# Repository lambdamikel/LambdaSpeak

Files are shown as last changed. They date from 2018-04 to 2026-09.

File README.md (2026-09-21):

# LambdaSpeak 
## A Next-Generation Speech Synthesizer & PCM Sample Player for the Amstrad / Schneider CPC, Multitech Microprofessor, and ZX Spectrum 
#### Author: Michael Wessel (Original Hardware Design and LambdaSpeak Firmware)
#### Contributors: Dr. Stefan Stumpferl (LambdaSpeak ROM and |RSX Driver), Bryce (some brainstorming about the hardware)
#### License: GPL 3
#### Homepage: [Author's Homepage](https://www.michael-wessel.info/) 

### Latest News

09-20-2026: The 1985 Vector Head speaks, on LambdaSpeak

In 1985 I digitized a wireframe head by hand off a P.M. Computerheft
article about computer graphics, using tracing paper and graph paper,
and wrote a Locomotive BASIC 1.0 program on my Schneider CPC 464 to
draw it. It has been my logo ever since.

Forty years on it has been rewritten in Z80 assembler, animated, and
given a voice. The head is drawn in 0.18 seconds instead of the 13.2
the BASIC took, and you can type any sentence and have it spoken, with
the lips, the jaw, the chin and the eyes moving on the allophones.
The text-to-speech is the Naval Research Laboratory letter-to-sound
algorithm, adapted from the 1985 Amstrad SSA-1 driver, so it runs on
LambdaSpeak in SSA-1 mode.

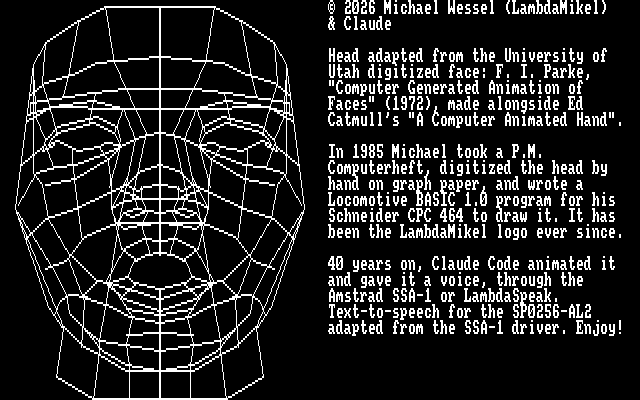
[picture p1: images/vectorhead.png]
The Vector Head


[Watch the YouTube demo video.](https://youtu.be/UzU3wziq7BQ)

[And here it is on LambdaSpeak 3.](https://youtu.be/XNuESTllX0o)

The disc is here: [head.dsk](cpc/vectorhead/head.dsk) for an emulator or a
real drive, and [head.hfe](cpc/vectorhead/head.hfe) for a Gotek or HxC.
Start it with `RUN"VH` - [here is how to run it.](cpc/vectorhead/) The
assembler source is not public yet.

12-16-2025: Direct Spectrum-to-CPC Adapter

This adds one Mx4 compatible expansion slot directly to the Spectrum,
without requiring the ribbon cable or Mx4-compatible backplane extender
(e.g., no LambdaBoard required). This looks much more organized indeed!

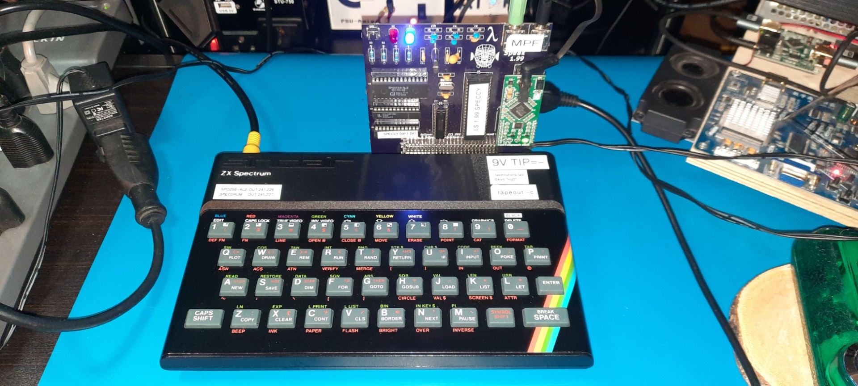
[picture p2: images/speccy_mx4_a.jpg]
Speccy Mx4 Adapter 1


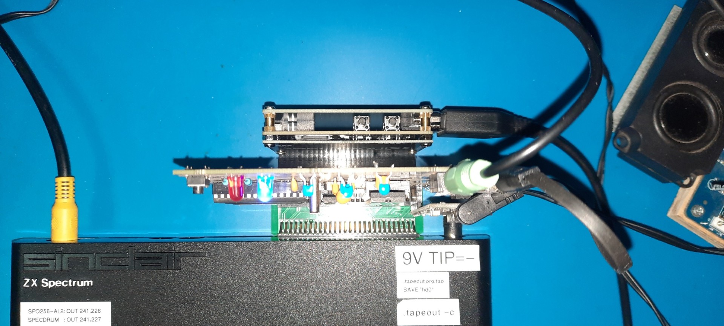
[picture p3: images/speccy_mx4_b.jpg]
Speccy Mx4 Adapter 2


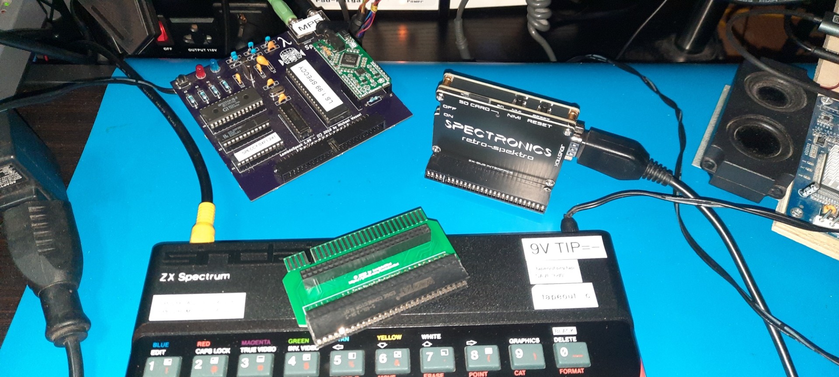
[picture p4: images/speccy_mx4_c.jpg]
Speccy Mx4 Adapter 3


[YT demo video.](https://www.youtube.com/shorts/BpbL_IXIipw?feature=share)

The Gerbers are [here](gerbers/zx-spectrum-mx4-direct-adapter-gerbers.zip)

12-07-2025: Cheetah Specdrum emulation is working:

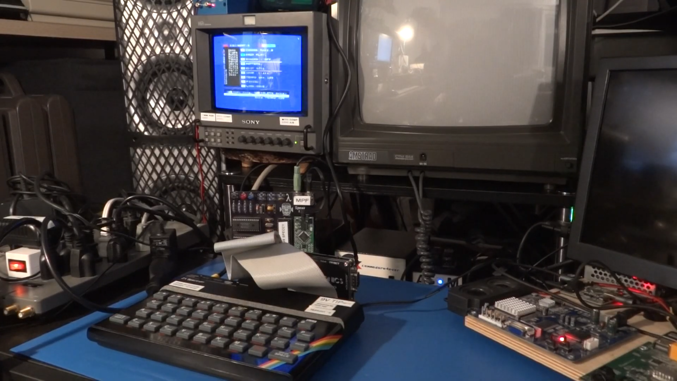
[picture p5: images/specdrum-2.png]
Specdrum 2

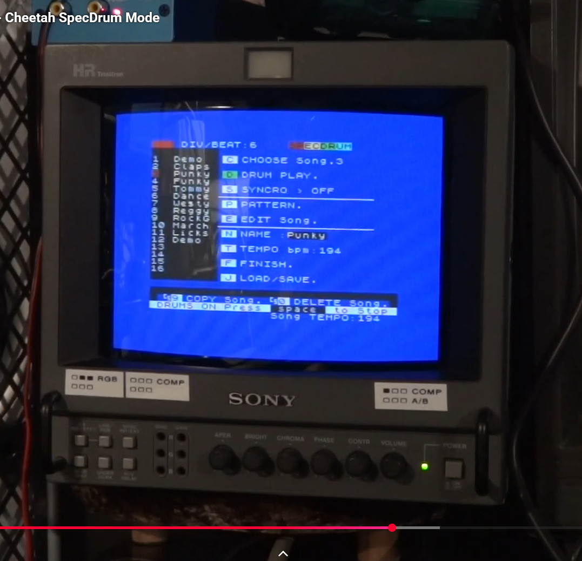
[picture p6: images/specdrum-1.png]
Specdrum 1


Check out [the SpecDrum emulation demo YouTube video.](https://youtu.be/OoMWcIEqiDU)

11-30-2025: I connected LambdaSpeak 1.99 to the ZX Spectrum!

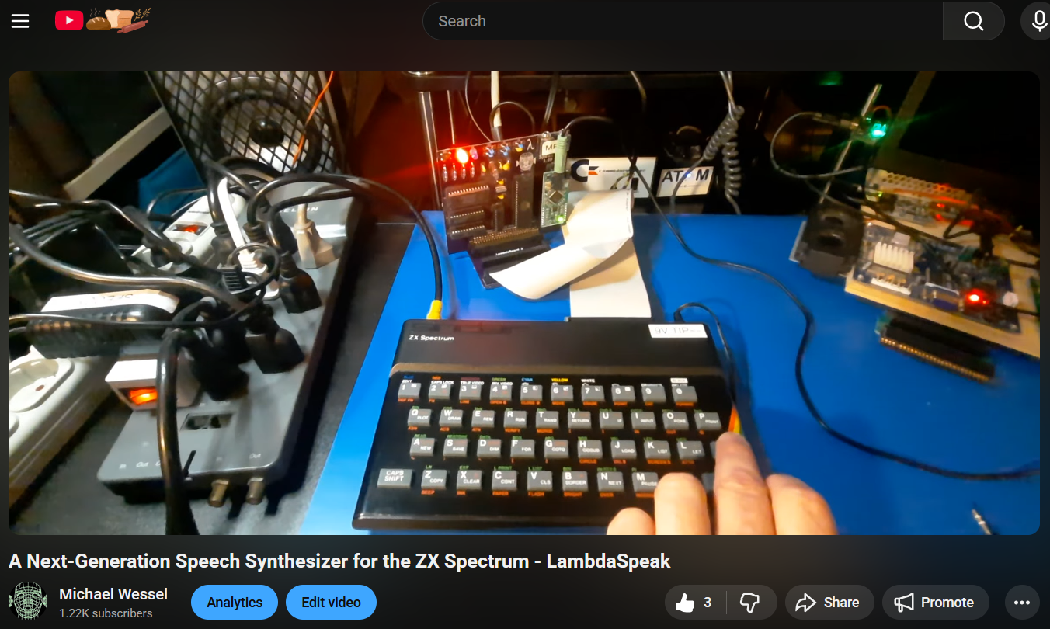
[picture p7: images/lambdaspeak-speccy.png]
LambdaSpeak 1.99 with the ZX Spectrum


[Watch the YouTube demo video.](https://youtu.be/x5bdC2Z1gy8)

To facilitate this, I have created a [ZX Spectrum to CPC Mx4 expansion
board adapter:](gerbers/zx-spectrum-adapter-gerbers.zip)

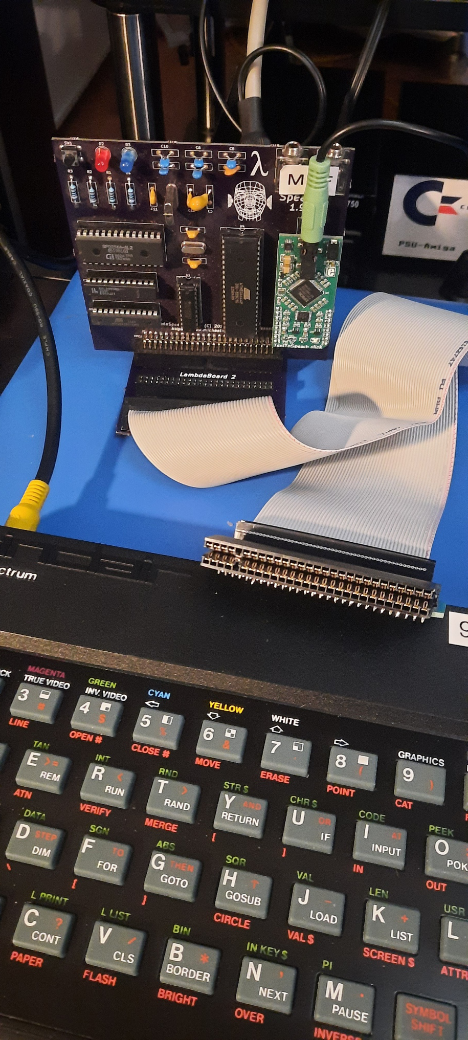
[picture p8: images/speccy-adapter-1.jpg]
Speccy Adapter 1

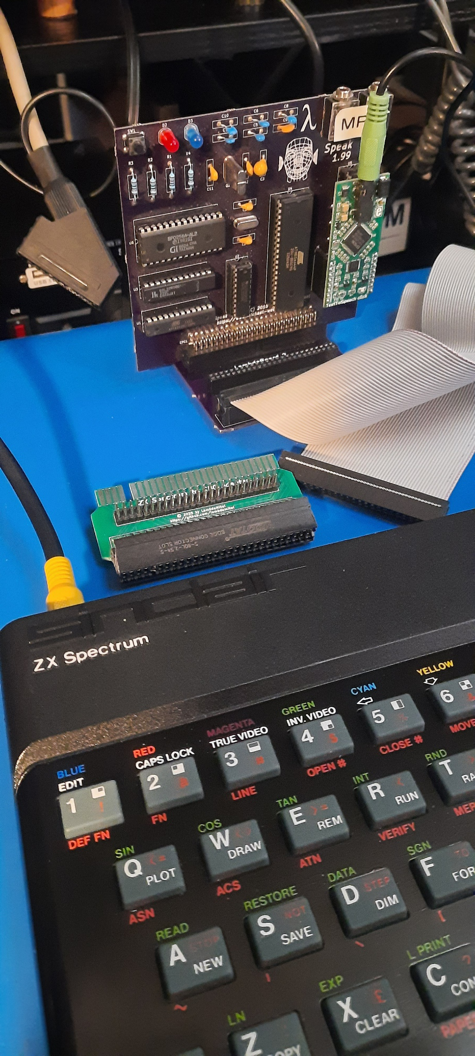
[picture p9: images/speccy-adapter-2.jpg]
Speccy Adapter 2


The adapter has a Speccy expansion port passthrough so that it will
work with other expansions as well (DivMMC, Interface I, ...). I have
only tested with the DivMMC so far, and no issues.

You will need an Amstrad CPC-compatible Mx4 expansion backplane, e.g.,
a [LambdaBoard](https://github.com/lambdamikel/LambdaBoard) or
[MegaLambda.](https://github.com/lambdamikel/MegaLambda-x6). Note that
the IDC female connector has the upper/lower pins flipped / mirrored, 
so you CAN NOT plug in the LambdaSpeak directly.

I changed the address decoder to listen to port `0x00F1` (`0xF1` =
`241`) for the Speccy. Also, only the non-blocking mode is working so
far - apparently, the Speccy doesn't like to be "halted". Hence, the
ATmega firmware needs a small change, too - see [line 5120 in the
`lambdaspeak.c` firmware:](src/atmega644-20pu/lambdaspeak.c)

```
	// note: for ZX Spectrum, remove / comment out this z80_halt: 
	z80_halt;
```

There is also a [ATmega HEX
image](firmware/atmega644/ls199-for-zx-spectrum-with-adapter/atmega644-20pu.hex)
and the [JED file for the `U1` address
decoder](firmware/ls199/gal22v10-zx-spectrum/LambdaSpeak-U1.jed) if
you want to try this yourself.

### Older News 

06-28-2025: I connected LambdaSpeak 1.99 to the Microprofessor. I
always longed for the SSB-MPF speech synthesizer with the TMS5200
chip, but they are pretty much unobtainium. But, LambdaSpeak 1.99 is
actually the better deal, due to natural sounding speech, built-in
text-to-speech (no allophone encoding required!), and in addition, is
also has the SP0256-AL2! My LambdaSpeak 1.99 was sitting unused in a
box for the last 7 years, and it was more than happy to shine again. I
needed to reprogram the GALs though; the address decoder listens to
port `0x00FE` now, and I removed all DK'tronics-related encoding as
well. It works!

https://www.youtube.com/watch?v=P0gi5Z2-3yM

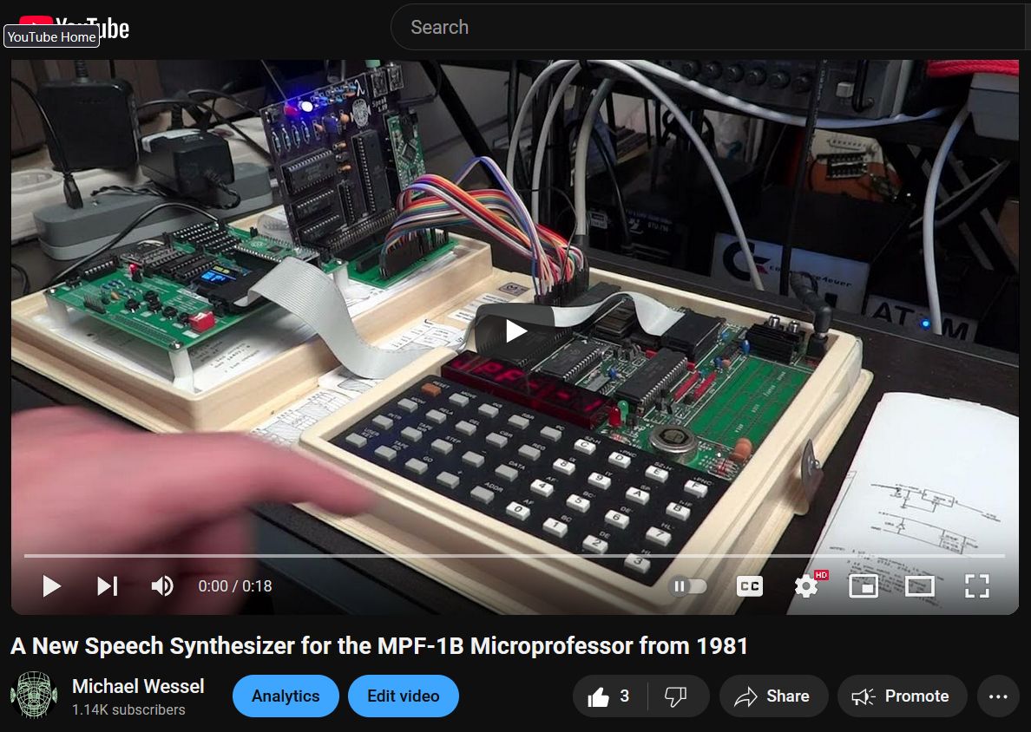
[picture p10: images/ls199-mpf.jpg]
LambdaSpeak 1.99 with the Microprofessor


The reprogrammed GALs are [here.](firmware/ls199/gal22v10-mpf/)

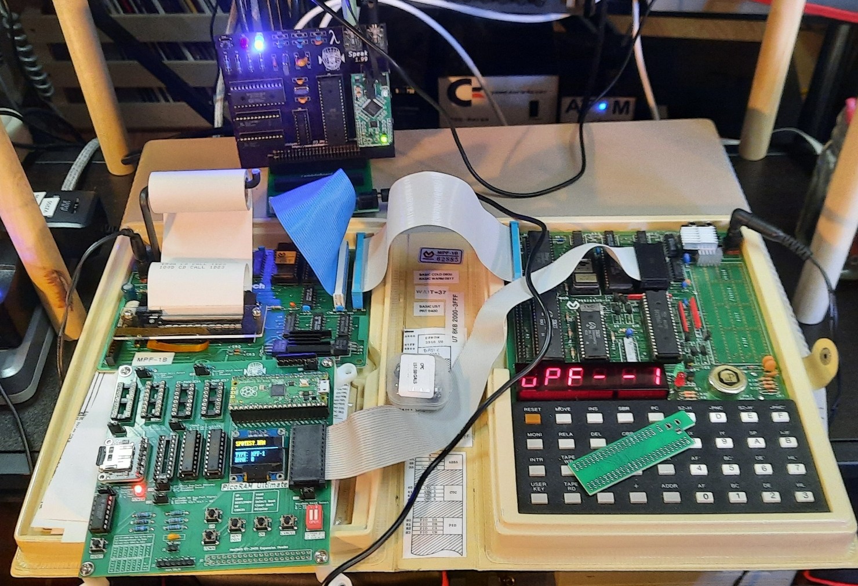
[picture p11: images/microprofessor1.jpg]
LambdaSpeak 1.99 with the Microprofessor 1

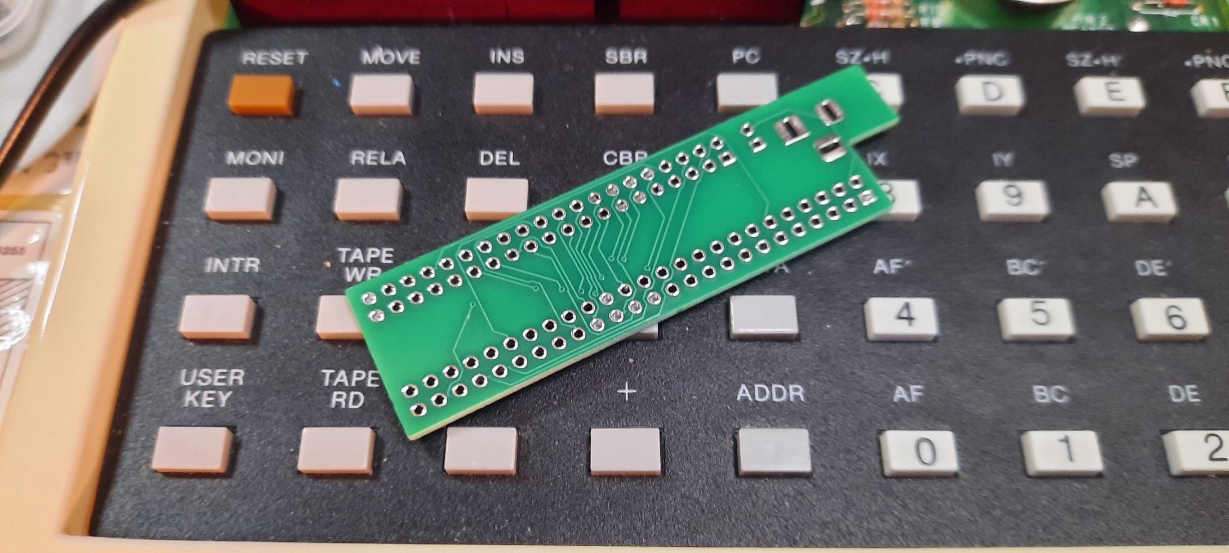
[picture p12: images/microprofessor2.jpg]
LambdaSpeak 1.99 with the Microprofessor 2

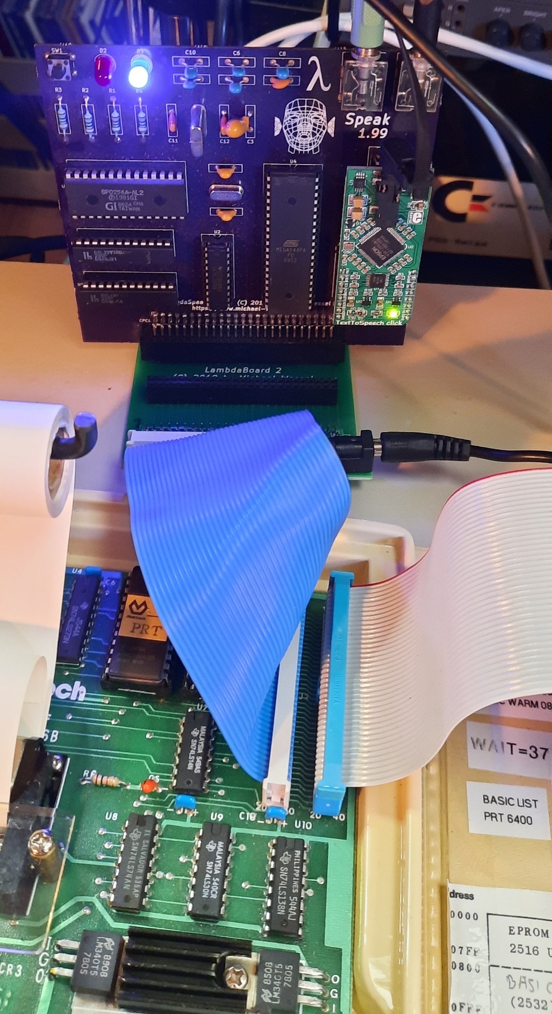
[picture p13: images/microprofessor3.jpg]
LambdaSpeak 1.99 with the Microprofessor 3

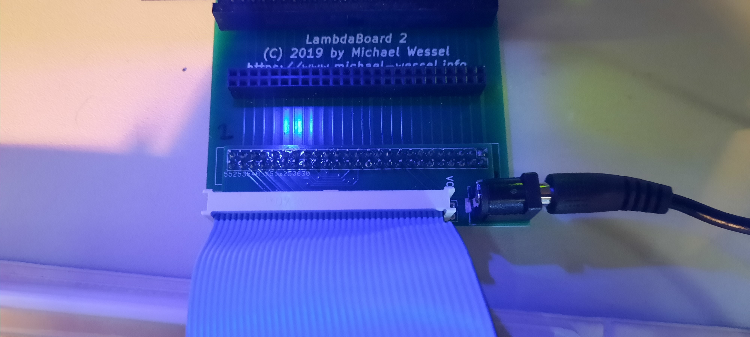
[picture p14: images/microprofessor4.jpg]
LambdaSpeak 1.99 with the Microprofessor 4


Here are [the Gerbers for the
adapter](gerbers/microprofessor-adapter-gerbers.zip), and here is
[a matching CPC backplane](https://github.com/lambdamikel/LambdaBoard). 

### Much Older News 

I have decided to publish [the WinAVR C sources for LambdaSpeak 1.95 and LambdaSpeak 1.99](src/atmega644-20pu/). The  [main C firmware file](src/atmega644-20pu/lambdaspeak.c) is shared among LambdaSpeak 1.95, LambdaSpeak 1.99, and LambdaSpeak 3, so please make sure to have `#define LS195` or `#define LS199` enabled.

### Important License Information

LambdaSpeak uses GPL 3. This code uses the [Epson S1V30120 firmware image]( https://github.com/MikroElektronika/Click_TextToSpeech_S1V30120/blob/master/library/include/text_to_speech_img.h)
from the [TextToSpeech click board library from MikroElektronika released under GPL2.](
https://github.com/MikroElektronika/Click_TextToSpeech_S1V30120) 
By using this code, you are also bound to the [Epson license terms for the S1V30120 firmware.](https://global.epson.com/products_and_drivers/semicon/products/speech/voice/sla/s1v30120_init_data.html)  

### Requirements 

This project was developed using
[WinAVR.](http://winavr.sourceforge.net/) In addition, the [AVR
Programming Libraries](https://github.com/hexagon5un/AVR-Programming)
from Elliot Williams' book "Make: AVR Programming" are being used. 

### Building and Maker Support 

I am able to provide LambdaSpeak 1.95 and LambdaSpeak 1.99 as a kit, or only pre-programmed components (CPLD, ATMega), or even a fully assembled version including
a connection cable and/or LambdaBoard expansion board backplane. Send me a mail if you are interested. Or, just download the sources and build it from the [provided Gerbers](gerbers/).

To build the [firmware from source,](src/atmega644-20pu/lambdaspeak.c) use `make` and the [provided `Makefile`](src/atmega644-20pu/Makefile). The makefile template is again from Elliot Williams' "AVR Programming" book. See below (Acknowledgements). 

### Introduction

**NOTE - This project is obsolete. Please refer to [the successor project, LambdaSpeak 3](https://github.com/lambdamikel/LambdaSpeak3)**

LambdaSpeak is a next-generation speech synthesizer and PCM sample player for the Amstrad CPC line of 8bit home computers from the 1980s (i.e, the CPC 464, CPC 664, and CPC 6128). 

LambdaSpeak is a MX4-compatible IO extension that plugs into the expansion port of the CPC.

LambdaSpeak is based on the **Epson S1V30120 TTS** (text to speech) chip. An **ATmega 644P-20PU** microcontroller clocked at 20 MHz is running the LambdaSpeak firmware, which implements a high-level intelligent interface to the CPC. The LambdaSpeak firmware / ATmega 644 is also responsible for hosting and loading the Epson firmware into the S1V30120, and for controlling the Epson speech chip via the SPI interface.  The Epson firmware is rather large; hence a microcontroller with a large (64 KB of) flash memory such as the ATmega 644 was selected. 

The Epson S1V30120 firmware implements two modes of operation: a DECtalk-compatible mode, and a simplified, native Epson mode. The latter is simpler and sometimes produces more accurate speech, whereas the former offers much more fine grained control over the speech synthesis process.  DECTalk is famous for being the "singing" speech synthesizer. 

LambdaSpeak 1.99 and LambdaSpeak 2.1 additionally feature the original **General Instruments SPO256-AL2 chip**, for 100% authenticity and compatibility with the original SSA-1 and DK'tronics speech synthesizers.  

### Features 

LambdaSpeak is a high-quality speech synthesizer for the Amstrad / Schneider CPC, based on the Epson S1V30120 speech chip. LambdaSpeak uses the [39$ "TextToSpeech click" board from MikroElektronika](https://www.mikroe.com/text-to-speech-click) as a daughter board. This board basically consists of the Epson IC, an op-amp, and an audio jack.  

LambdaSpeak also implements the **Amdrum module**, a PCM sample-based drum computer for the CPC. 

Optionally, LambdaSpeak can be equipped with a second speech chip, the original **SPO256-AL2** from General Instruments ano 1981.        

The following modes of operation are implemented by the **LambdaSpeak firmware** that runs on the ATmega 644:   

  1. **Native Epson Mode:** Native because the TTS is directly performed by the Epson IC / firmware. In this mode, a stream of ASCII characters can be sent to CPC IO port &FBEE, terminated by CR (13), and the assembled ASCII string will be spoken by LambdaSpeak. Voice, volume, and speed of the speech can be changed as well.  

  2. **Native DECtalk Mode:** The DECtalk emulation offers much more fine-grained control over different aspects of the generated speech. These aspects are specified using the standard DECtalk syntax, down to the level of phonemes if desired. In this mode, LambdaSpeak can even sing a song! Again, CPC IO port &FBEE is used. 
  
  3. **SSA-1 mode:** In this mode, LambdaSpeak emulates the **Amstrad SSA-1 Speech Synthesizer**. The SSA-1 synthesizer uses a very different speech chip, the **SPO-256 AL2 from General Instruments**. This chip offers phoneme-based speech synthesis. The emulation of the SSA-1 is achieved by translating SPO-256 AL2 phonemes into DECtalk phonemes. Whereas the SSA-1 works synchronously, i.e., a phoneme is immediately uttered as soon as it arrives at the port, this is not possible with the Epson chip. Hence, LambdaSpeak employs a phoneme buffer (of 380 characters) which is first filled with phonemes, and the buffer is flushed and spoken if no phoneme has arrived for a couple of milliseconds (the buffer flush delay time if configurable). The buffer is also flushed automatically when it overflows, and a corresponding "flush buffer" command / "control byte" also exists (see below). Hence, the SSA-1 emulation works asynchronously, and a slight delay between phoneme sending and speaking should be expected. The SSA-1 uses IO ports &FBEE and &FAEE.  Please note that it is impossible to emulate the low-quality robotic sound of the SPO-256 AL2 with a modern speech IC such as the Epson S1V30120. Hence, the SSA-1 emulation will actually produce understandable speech that sounds much better than the original, but it is not 100% authentic to the original. The emulation, due to its asynchronous character, is only 90%, but good enough for most of the SSA-1 driver |RSX commands and games to work flawlessly. See below for videos of the SSA-1 mode. 
       
  4. **DK'tronics mode:** In this mode, the **DK'tronics Speech Synthesizer** is emulated. The DK'tronics synthesizer uses IO port &FBFE. It is very similar to the SSA-1, and uses the same SPO-256 AL2 speech chip from General Instruments. However, the driver software and |RSX extension are different, and a different "protocol" is implemented. Unlike for the SSA-1, a ROM version of the DK'tronics driver software exists. The DK'tronics driver software implements a less advanced text-to-phoneme speech translation algorithm than the SSA-1 driver software; the latter sounds much better, IMHO. The LambdaSpeak implementation of the DK'tronics speech synthesizer works similar to the SSA-1 emulation, i.e., a phoneme buffer and auto-flushing (and speaking) of the phoneme buffer after a configurable flush buffer time delay of inactivity is performed. Similar comments regarding the authenticity and compatibility as for the SSA-1 mode apply to the DK'tronics emulation.

  5. LambdaSpeak 1.99 and LambdaSpeak 2.1 can be equipped with an optional **GI SPO256-AL2 speech chip**. Thus, a **SPO256-AL2-based SSA-1 mode** is offered, being 100% compatible and authentic to the original SSA-1. In this mode, LambdaSpeak can be considered a re-implementation of the original SSA-1. Unlike the Epson-based SSA-1 emulation, this mode works synchronous, like the original. 
  
  6. With the SPO256-AL2 speech chip being present, a **SPO256-AL2-based DK'tronics mode** is offered, which is 100% compatible and authentic to the original DK'tronics speech synthesizer. Like the SPO-based SSA-1 mode, this mode works synchronous as well, just like the original. 

  7. An 8bit PCM Sample Player, emulating the **Amdrum module**. In **Amdrum mode**, 8bit PCM samples can be sent to IO port &FFxx, which are being played immediately by LambdaSpeak. To quit this mode, LambdaSpeak needs to be power cycled (even the LambdaSpeak reset button is ineffective in this mode, as ATmega 644 interrupts are disabled for maximal sample playing quality). The PCM audio is produced by the ATmega 644 microcontroller.      

LambdaSpeak has an **op-amp-based audio mixer on board,** which is used to mix the PCM output with the (potentially present) SPO256-AL2 output and the speech audio from the "TextToSpeech click" daughter board. Since the audio output of the daughter board is **only** available from its audio jack, but not from the output header pins of the click board, a (short, e.g, 2") audio jumper cable has to be used to route its speech output into LambdaSpeak's audio input for mixing. 

### Media 

A couple of pictures and YouTube videos. Please notice that **the voltage SMD jumper of the TextToSpeech click daughter board must be set to the 5V position (requires soldering).**  

#### **LambdaSpeak 1.95**: 

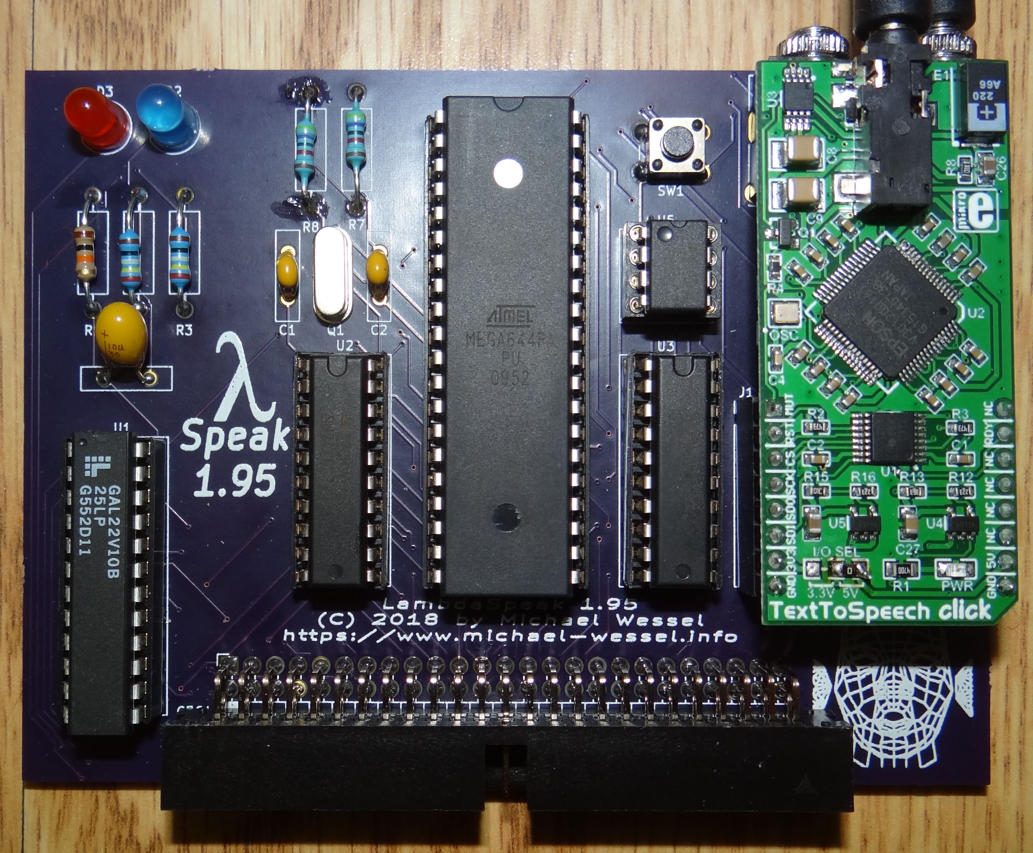
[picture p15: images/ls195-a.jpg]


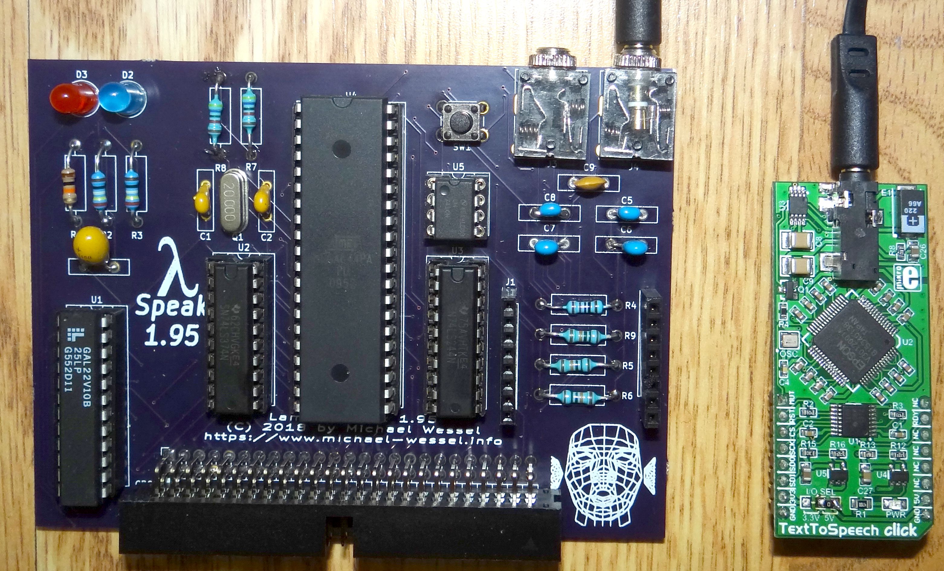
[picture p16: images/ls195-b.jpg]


#### **LambdaSpeak 1.99** with additional GI SPO256-AL2:   

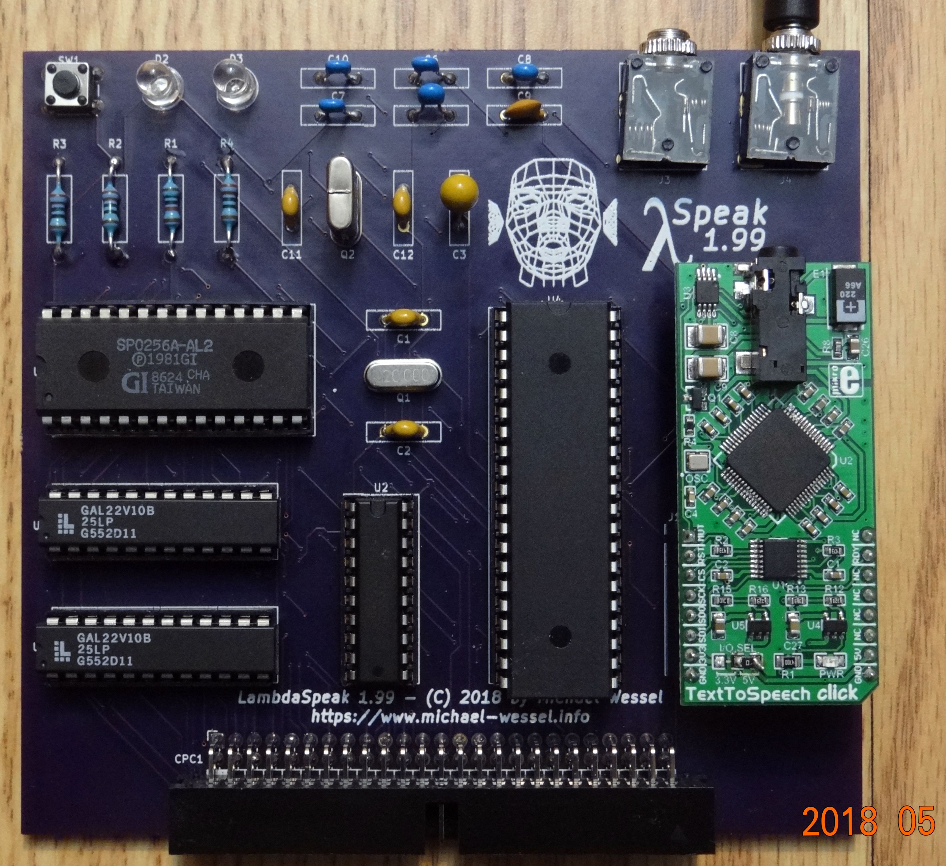
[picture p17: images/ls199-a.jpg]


#### CPC Connection: 

LambdaSpeak is **MX4 compatible** and can either be plugged into the Mother X4 board, a standard 50-pin ribbon cable, or my [MX4 compatible CPC 464 expansion port adapter for the CPC 464](https://oshpark.com/shared_projects/3yA33GYO) can be used:  

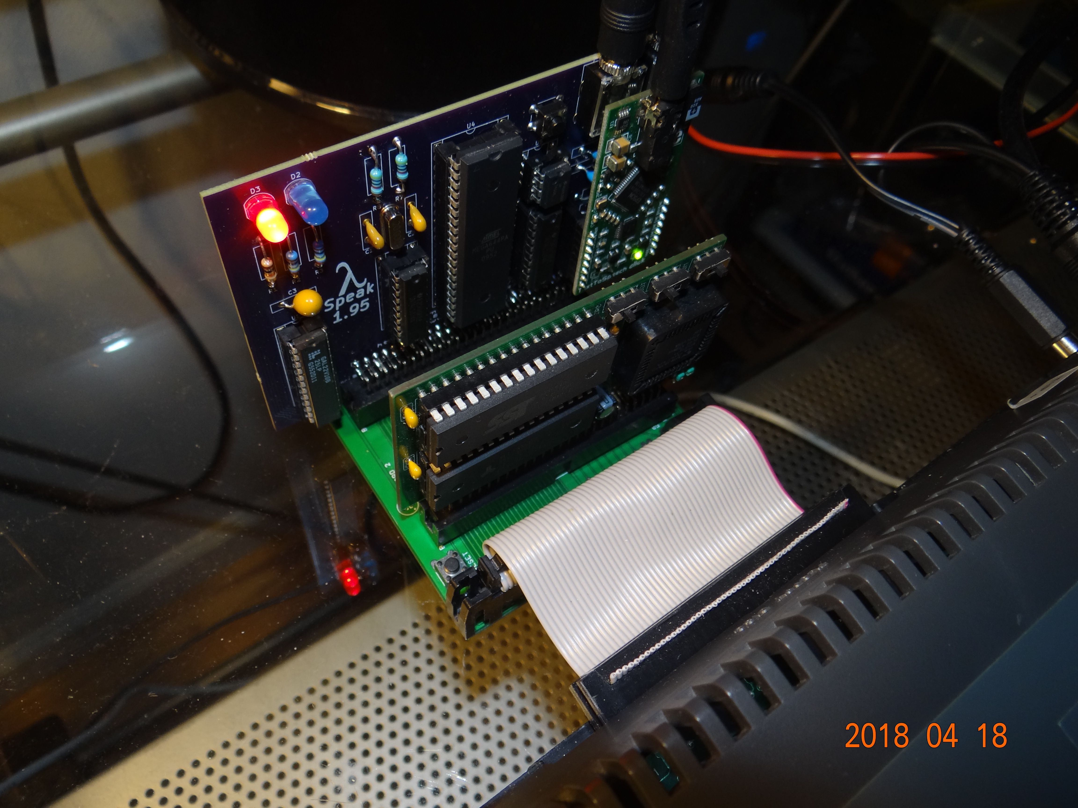
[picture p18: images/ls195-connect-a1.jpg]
LambdaSpeak & XMem in Mother X4 Board


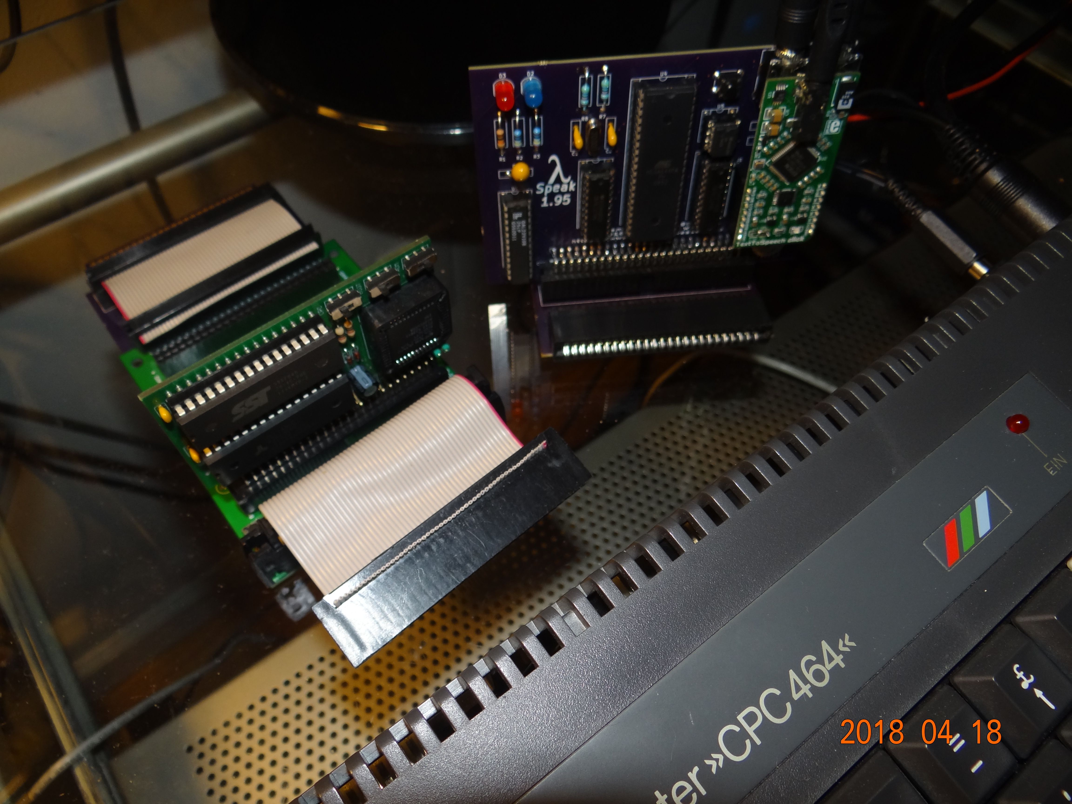
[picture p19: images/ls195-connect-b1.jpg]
LambdaSpeak & 464 Expansion Port Adapter


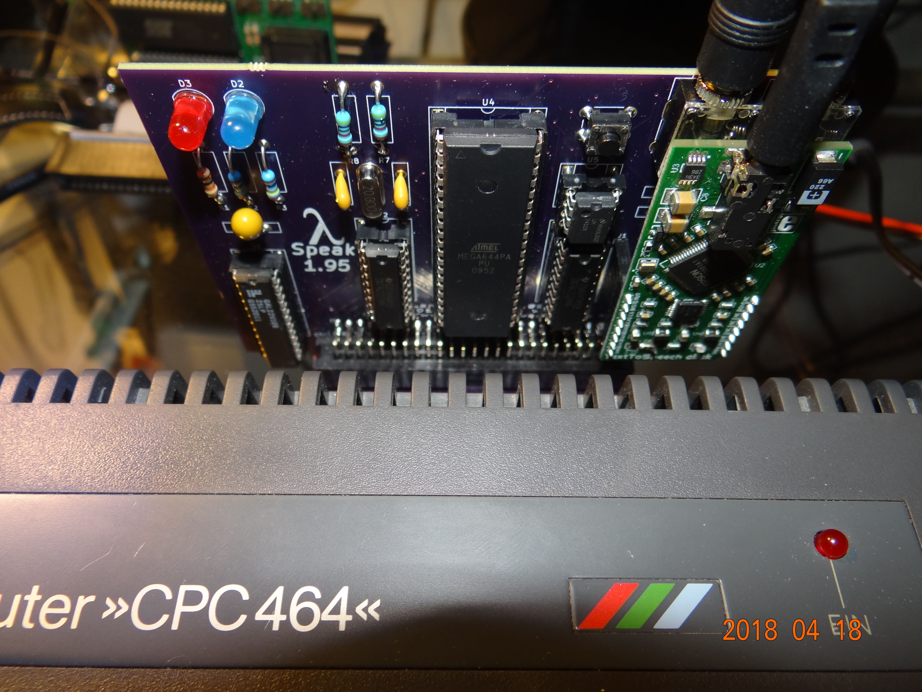
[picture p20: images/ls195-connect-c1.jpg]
LambdaSpeak & 464 Expansion Port Adapter in CPC


#### YouTube Videos 

Below are a couple of YouTube videos that demonstrate the various features and modes of LambdaSpeak. Notice that (some of) these videos are showing older versions of the LambdaSpeak hardware, but there is no difference in functionality. Also, speech quality etc. is identical to the current version of LambdaSpeak:  

- [LambdaSpeak Native Mode - talking ELIZA Program](https://youtu.be/ckCTHi5_2f8)
- [LambdaSpeak DK'tronics & SSA-1 Emulation - German-speaking ELIZA program, originally written for the DK'tronics speech synthesizer](https://youtu.be/aTxufTKfrYk) 
- [LambdaSpeak and DK'tronic Speech ROM Software](https://youtu.be/wxNSlEyfPMc)
- [TFM's LambdaSpeak |RSX Driver](https://youtu.be/CsaE9JfhJ20)
- [Sample Playing in "Amdrum mode" with TFM's |RSX Driver](https://youtu.be/RSu7fPpDmCQ)
- [PCM Audio Quality of Amdrum Mode using Amdrum Software](https://youtu.be/pBuBxT3YEuI)
- [Amdrum Demo](https://youtu.be/upVayBKlnow)
- [Another Amdrum Demo](https://youtu.be/E63uH6SpzMs)
- [LambdaSpeak 2.1 Breadboard Prototype with additional SPO256-AL2](https://youtu.be/Og3qyQo9nfw)

#### Older Versions

The historical **LambdaSpeak Ancestry Gallery** shows early versions of LambdaSpeak. Some early versions were using the **Emic 2** TTS daughterboad (bottom left PCB) instead of the "TextToSpeech click" from Elektronika: 

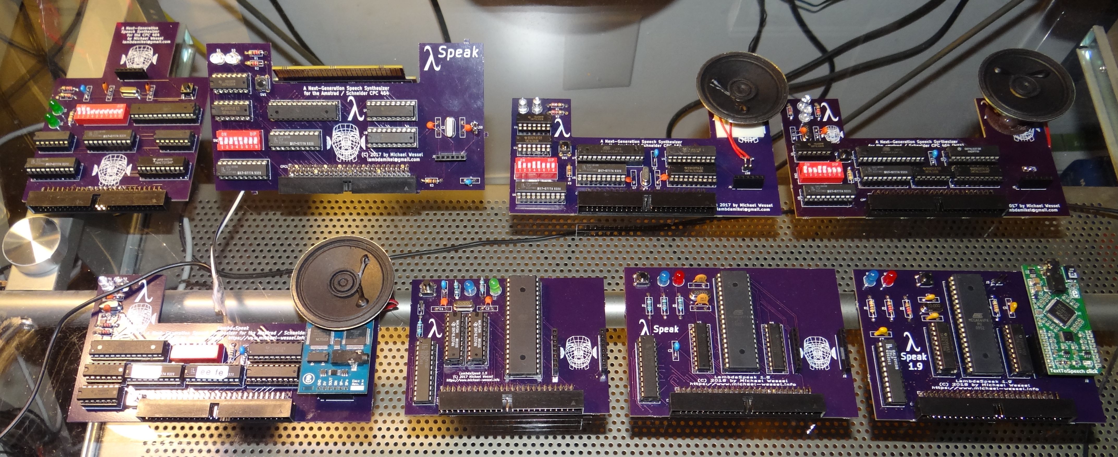
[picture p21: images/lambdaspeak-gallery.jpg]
LambdaSpeak Gallery


The versions, from top left to bottom right: 

 - LambdaSpeak 0 - no SSA1 or DK'tronics emulation, hand-soldered additional Z80 \_READY line at the bottom to correct for a design flaw. Emic 2 based, ATmega328p, 2 GAL16V8s. Not MX4 compatible. DIP switches are used to select port addresses etc. Clocked at 16 MHz. 
 
 - LambdaSpeak 1 - tried to make it fit with DDI3 display behind, but would still block the display due to miscalculation / bad measurements. SSA1 emulation required additional logic gate. Not MX4 compatible, \_READY line fixed. Added loudspeaker option. 
 
 - LambdaSpeak 1.2 - improvement over LambdaSpeak 1, no longer blocks DDI3 display. Otherwise identical to LambdaSpeak 1, but with little loudspeaker added. Loudspeaker can be en/disabled via DIP switch, DIP switches also select initial mode (SSA1 or native), Port Address, etc.
 
 - LambdaSpeak 1.3 - same as LambdaSpeak 1.2, but tried to make it MX4 compatible. Due to an error in the layout, it STILL was not MX4. Was working perfectly fine, just not MX4 compatible. 
 
 - LambdaSpeak 1.4 - the final version before hardware revision. Now MX4 compatible. 
 
 - LambdaSpeak 1.5 - new hardware version, triggered by input from Bryce who suggested to abandon the Emic 2 to bring the costs down (Emic 2 ~ 80 $). DKtronics emulation possible. No more DIP switches. Switched to ClickBoard! TextToSpeech daughter board, much cheaper than Emic 2, but requires bigger MCU now - selected the ATmega 644p with 64 KB @ 20 MhZ. A lot of flash memory is required to store and load the Epson S1V30120 speech IC firmware. Also, replaced the 2 GAL G16V8 and the glue logic with one GAL G22V10. <br /> In this version, the firmware supports DKtronics emulation by now. New design, uses 2 74LS374 flip flops instead of 1 74LS374 and 1 74LS244. Hence, chip count reduced from 7 to 4 (not counting the chips on the daughter boards). Also, the databus to the ATmega 644 is shared. Requires rather complicated triggering of input / output flip flops from the ATmega, and toggling of ATmega data port between input and output mode. Works, but too cumbersome and not as fast due to complicated clocking required for the flip flops. But easier to layout, as most of the ATmega 644's pins are unused. No more loudspeaker; audio jack output from speech daughter board. Clocked at 20 MHz.
 
 - LambdaSpeak 1.8 - switched back to having 1 74LS374 input flipflop and 1 74LS244 output driver with dedicated, permanent data connection to the ATmega instead of 2 flip flops with shared data bus. Requires no complicated flip flop clocking / control from the ATmega, but takes more lines. Faster.
 
 - LambdaSpeak 1.9 - early version, with Amdrum emulation / Sample Player output, suggested by zhulien. Firmware supports PCM sample playing and Amdrum emulation mode. Dedicated RC and line output for PCM via simple pin header on the board, no audio jack yet, and no audio mixer on board. The PCM header is on the left top next to the daughter board. Speech daughter board has independent audio jack output, of course. 
    
### Hardware Overview 

In the following, 4 versions of LambdaSpeak are being discussed:

* **LambdaSpeak 1.95 and LambdaSpeak 1.99** use through-hole components and GAL22V10 PLDs, and PCBs and Gerber files exist. LambdaSpeak 1.99 supports the SPO256-AL2 as a second (optional) speech chip. 

* **LambdaSpeak 2.0 and LambdaSpeak 2.1** only exist as (fully functional) breadboard prototypes. They use a single Xilinx XC9572XL CPLD instead of the GALs. No PCBs or Gerber files exist yet. Bryce suggested to use a Xilinx CPLD. LambdaSpeak 2.1 supports the SPO256-AL2 as a second (optional) speech chip.  

Let us discuss these versions in more detail in the following.

All LambdaSpeak versions require the Epson S1V30120 Text-to-Speech Speech Synthesizer IC. The [39$ "TextToSpeech click" board from MikroElektronika](https://www.mikroe.com/text-to-speech-click) is used as a daughter board. It is plug and play, but requires re-soldering of an SMD jumper (from 3.3 V to 5 V position).   

#### LambdaSpeak 1.95 Overview

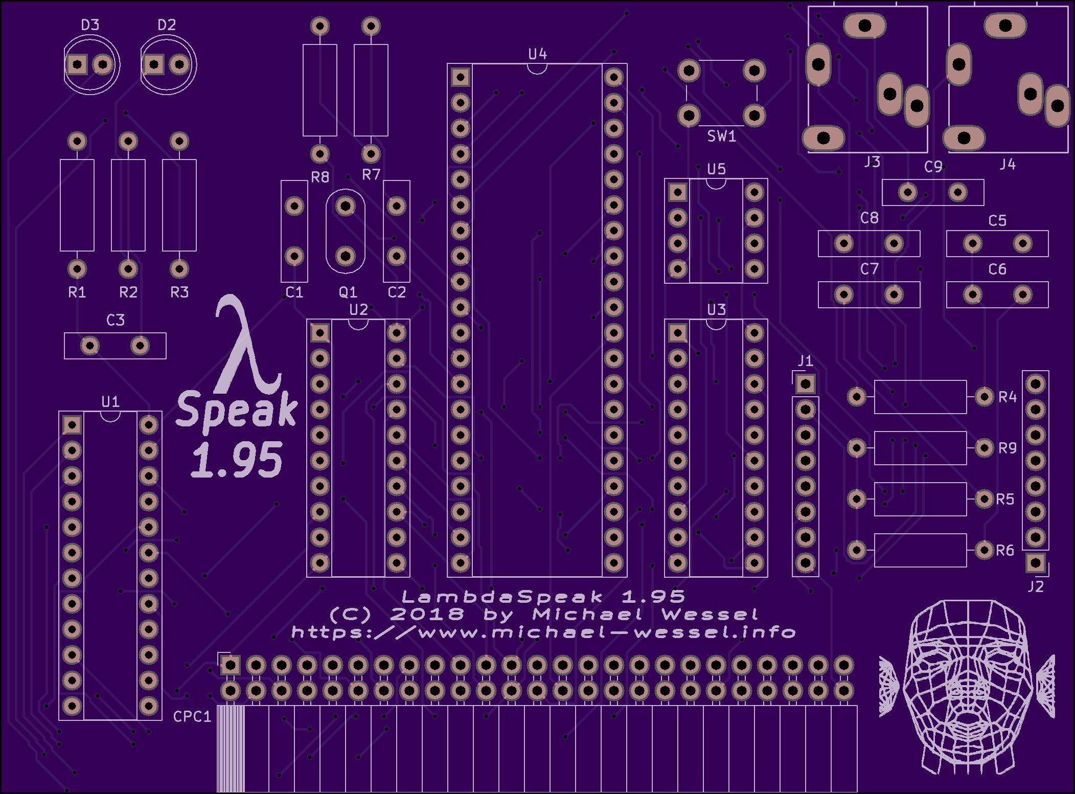
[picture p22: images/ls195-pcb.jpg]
LS 1.95 PCB


The main components are:

1. The [TextToSpeech click board from MikroElektronika](https://www.mikroe.com/text-to-speech-click) is used as a daughter board.  
2. ATmega 644P-20PU Microcontroller clocked at 20 MHz (U4). 
3. GAL22V10 Programmable Logic Device (U1), for Z80 address decoding and some glue logic. This is a discontinued component, but still easy to get on EBay. 
4. A 74LS374 flip flop (U2) for latching and buffering (input from) the CPC databus (handles IO write requests).
5. A 74LS244 bus driver (U3) for putting data on the CPC databus (handles IO read requests).
6. A LM741CN op-amp (U5) for mixing PCM output (produced by the ATmega 644) with the speech output from the Epson S1V30120 such that only one audio cable from LambdaSpeak is required. 

LambdaSpeak 1.95 Documents: 

* [Schematics (PDF)](schematics/lambdaspeak-195-schematics.pdf)
* [PCB](images/ls195-pcb.jpg)
* [Overview](images/ls195-pcb1.jpg)
* [3D Model](images/ls195-pcb2.jpg)
* [ATmega Pin Assignments](firmware/atmega644/ls195-and-ls20/ls195-ls20-pins.h) 
* [GAL22V10 PLD File & Pin Assignments](firmware/ls195/gal22v10/ls195-address-decoder-U1.PLD) 

Gerbers: 

* [Gerbers can be found here](gerbers/ls195/)
* [Also shared on OshPark for immediate ordering](https://oshpark.com/shared_projects/C2toYu43) 

##### Bill of Material for LambdaSpeak 1.95  

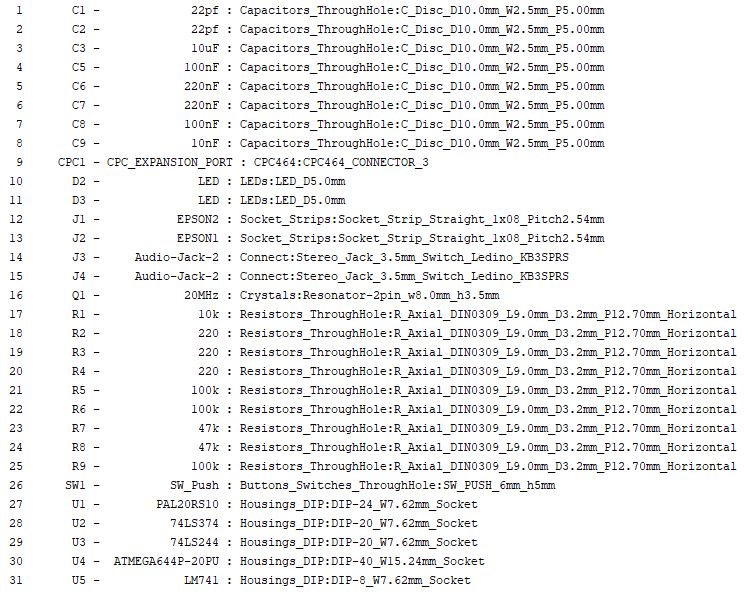
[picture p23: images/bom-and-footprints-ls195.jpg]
Bill of Material and Footprints from KiCAD


In addition, I suggest to use standard stackable Arduino Headers for J1, and J2, for plugging in the speech daughter board (instead of soldering it in permanently). A standard 2x25 angled IDC Box Header can then be used to plug LambdaSpeak into the **Mother X4 board**, to connect a 50 pin ribbon cable, or to plug it into [my CPC 464 expansion port connector](https://oshpark.com/shared_projects/3yA33GYO).

The form factors in the above BOM are **for illustration only.** Instead of ceramic disc capacitors, I have used ceramic multilayer capacitors mostly. I recommend using DIP sockets at least for the GAL22V10 and for the ATmega 644, such that they can be reprogrammed / reflashed easily when a new firmware arrives.

##### Notes on the Audio Section 

**The audio section is completely optional.** If you don't require audio mixing, just route the "Amdrum" PCM output directly to audio output jack J4, and you wont need J3 at all. This can be achieved by connecting a cable between C6 and C8 (check the schematics), and by omitting all of the audio circuitry. You will still need the RC for Amdrum mode though, i.e., C5 and R4 are still required. In this configuration without audio circuitry, the resistors R7, R8, R9, the J4 audio jack, and capacitors C6, C7, C8, C9, and the op-amp U5 can be omitted. Speech output then comes directly from the daughter board's audio jack. It is also convenient to at least keep audio jack J4 for Amdrum PCM output, as described. 

By default, **only the left channel of the stereo output audio jack is being used.** To route the signal to both channels, apply the following modification and bridge the 2 audio jack pins with a cable as shown in the following picture: 

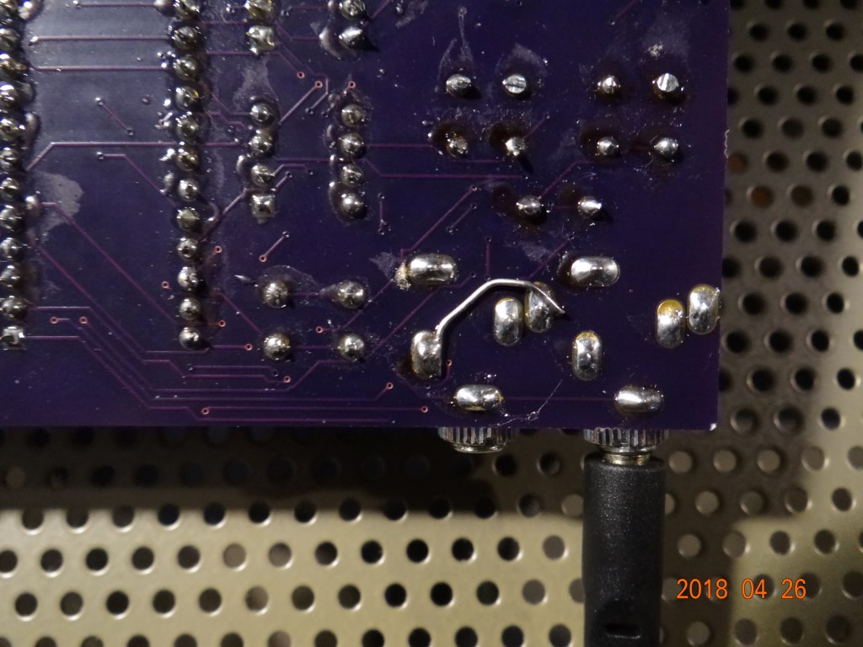
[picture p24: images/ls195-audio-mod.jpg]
Stereo Audio Modification


#### LambdaSpeak 1.99 Overview

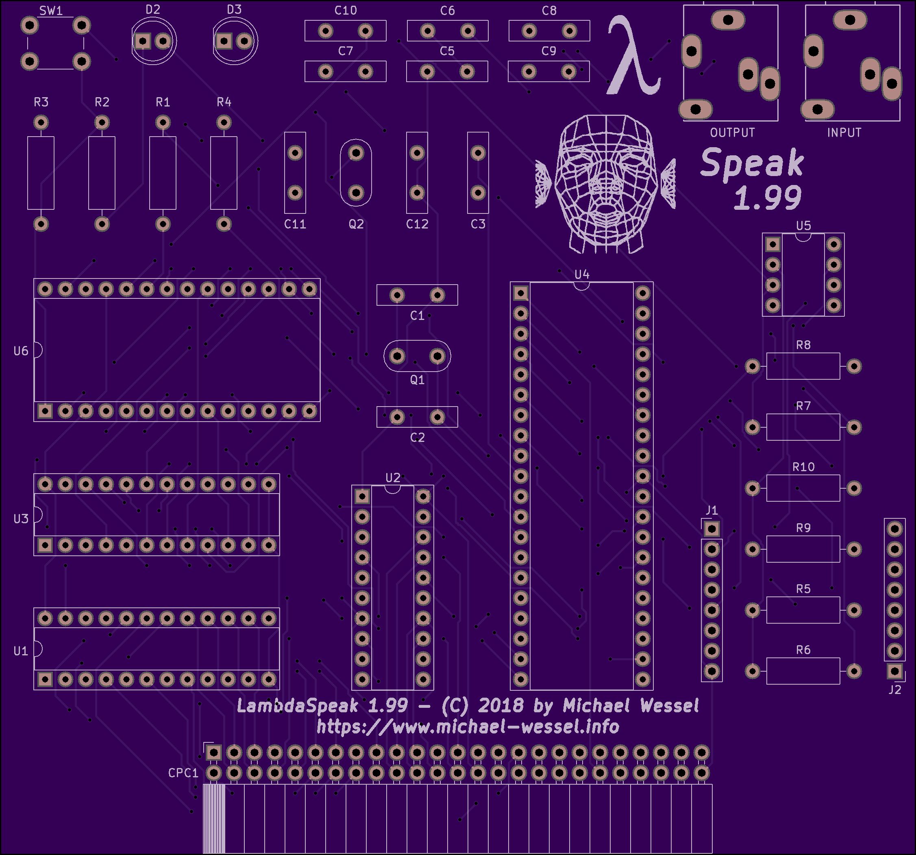
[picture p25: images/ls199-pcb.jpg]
LS 1.99 PCB
 

The main components are:

1. The [TextToSpeech click board from MikroElektronika](https://www.mikroe.com/text-to-speech-click) is used as a daughter board.  
2. ATmega 644P-20PU Microcontroller clocked at 20 MHz (U4). 
3. GAL22V10 Programmable Logic Device (U1), for Z80 address decoding and some glue logic. This is a discontinued component, but still easy to get on EBay. 
4. A 74LS374 flip flop (U2) for latching and buffering (input from) the CPC databus (handles IO write requests).
5. Another GAL22V10 Programmable Logic Device (U3), for presenting data to the CPC databus, and for multiplexing and reorganizing data depending on the current mode (handles IO read requests). 
6. A LM741CN op-amp (U5) for mixing PCM output (produced by the ATmega 644) with the speech output from the Epson S1V30120 such that only one audio cable from LambdaSpeak is required. 
7. The original GI SPO256-AL2 from 1981, clocked at 3.12 MHz. 

Documents: 

* [Schematics (PDF)](schematics/lambdaspeak-199-schematics.pdf)
* [PCB](images/ls199-pcb.jpg)
* [Overview](images/ls199-pcb1.jpg)
* [3D Model](images/ls199-pcb2.jpg)
* [ATmega Pin Assignments](firmware/atmega644/ls199-and-ls21-with-spo256-al2/ls199-ls21-pins.h) 
* [Address Decoder GAL22V10 PLD File & Pin Assignments (U1)](firmware/ls199/gal22v10/ls199-address-decoder-U1.PLD) 
* [Databus Multiplexer GAL22V10 PLD File & Pin Assignments (U3)](firmware/ls199/gal22v10/ls199-databus-multiplexer-U3.PLD) 

Gerbers: 

* [Gerbers can be found here](gerbers/ls199/)
* [Also shared on OshPark for immediate ordering](https://oshpark.com/shared_projects/JyRKoPdz) 

##### Bill of Material for LambdaSpeak 1.99  

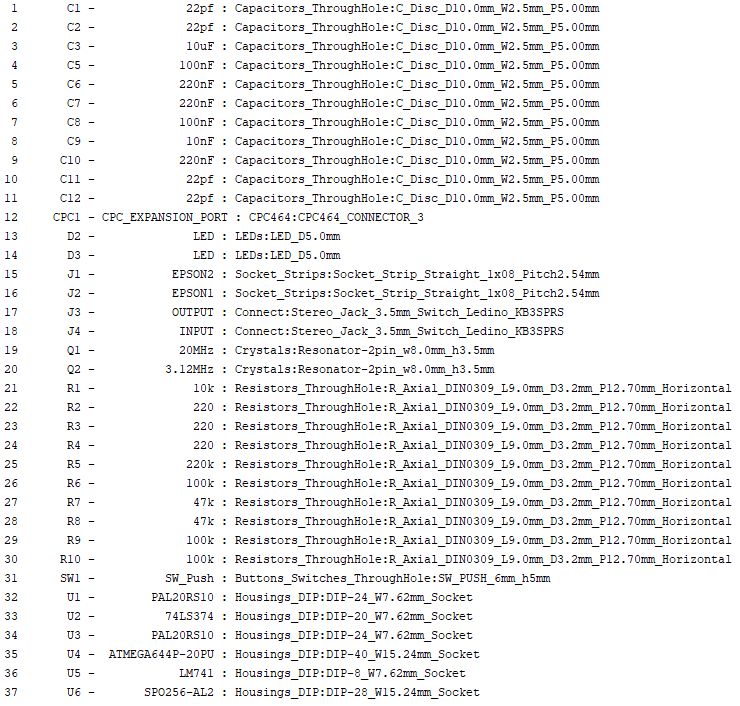
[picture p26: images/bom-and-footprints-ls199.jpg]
Bill of Material and Footprints from KiCAD


Same comments as for LambdaSpeak 1.95. The SPO256-AL2 (U6) is difficult to source; Ebay might be your best bet. Sometimes, counterfeits are being sold. The 3.12 MHz quartz oscillator can be  substituted with a 4 MHz oscillator, but the speech will have a higher pitch and be harder to understand. 

Notice that **the SPO256-AL2 section is completely optional**. It will also work with out a SPO256-AL2.  

##### Notes on the Audio Section 

As for LambdaSpeak 1.95, the audio section is completely optional, though you won't be able to hear the SPO256-AL2 nor the Amdrum mode then. 

Please notice that this time I have wired up the audio jacks for left and right channel! The output is mono, of course, but routed to both left and right channel. Hence, the audio "both channels" modification as shown for LambdaSpeak 1.95 above is not necessary for LambdaSpeak 1.99.  

#### LambdaSpeak 2.0 Overview

This version is equivalent to LambdaSpeak 1.95. The ATmega firmware is the same, but the GAL22V10, 74LS244 and 74LS374 are substituted by a single **Xilinx XC9572XL CPLD** (QFP-64  encapsulation). Moreover, an SMD version of the ATmega 644P-20PU will be used, reducing the chip count by 2. 

A working breadboard prototype of LambdaSpeak 2.0 exists, but no (SMD) PCB has yet been designed.

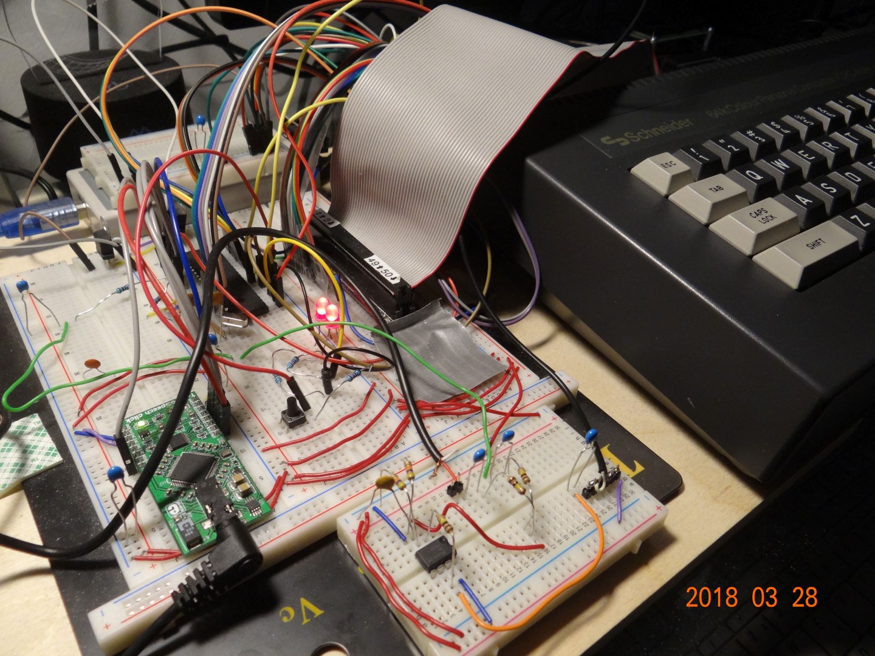
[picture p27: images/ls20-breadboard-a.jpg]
LambdaSpeak 2.0 Breadboard Prototype


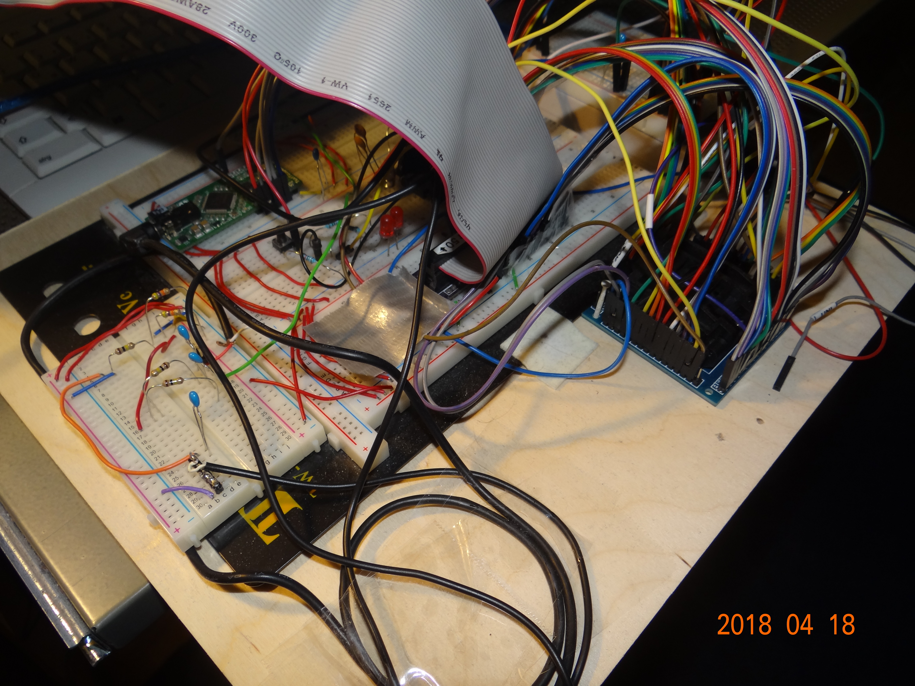
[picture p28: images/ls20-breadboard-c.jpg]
LambdaSpeak 2.0 Breadboard Prototype


Take a look at the [pin allocations for the Xilinx CPLD](firmware/ls20/xilinxXC9572XL/Main.ucf) and the [pin assignments for the ATmega](firmware/atmega644/ls195-and-ls20/ls195-ls20-pins.h); the latter one is identical with LambdaSpeak 1.95. Also, the [ATmega 644 firmware](firmware/atmega644/ls195-and-ls20/ls195-ls20-firmware.hex) is the same for LambdaSpeak 1.95; hence, the only difference between LambdaSpeak 1.95 and LambdaSpeak 2.0 is the firmware for the GAL / CPLD.   

The schematics are not given here, but take a look at the [pin allocations for the Xilinx CPLD](firmware/ls20/xilinxXC9572XL/Main.ucf) and the [pin assignments for the ATmega](firmware/atmega644/ls195-and-ls20/ls195-ls20-pins.h) from which the schematics can be deduced easily.

#### LambdaSpeak 2.1 Overview 

This adds the SPO256-AL2 to LambdaSpeak 2.0. It is equivalent to LambdaSpeak 1.99; the ATmega firmware is the same (difference is, again, in GAL vs. Xilinx CPLD hardware and reduced chip count, same as LambdaSpeak 1.95 vs. LambdaSpeak 2.0).

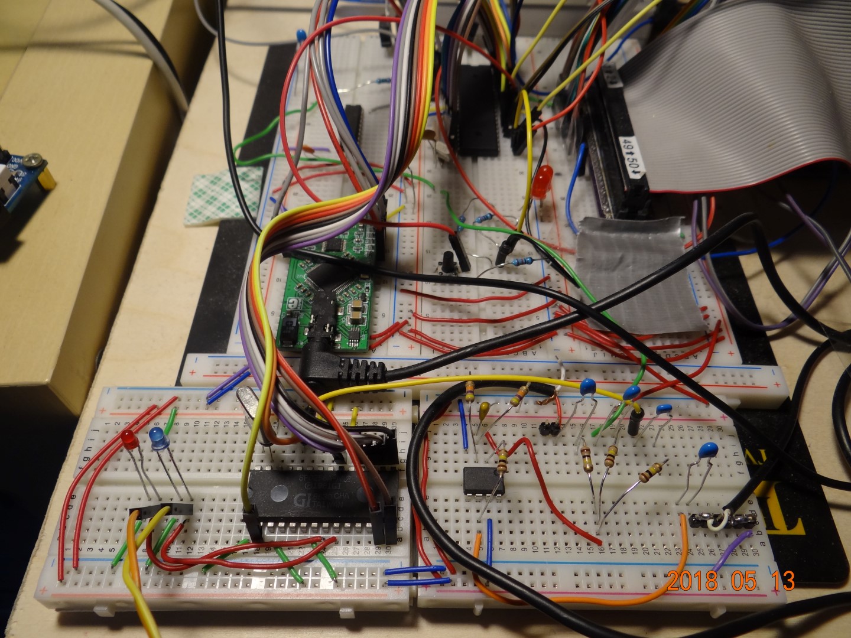
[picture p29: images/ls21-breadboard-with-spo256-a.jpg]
LambdaSpeak 2.1 Breadboard Prototype with SPO256-AL2


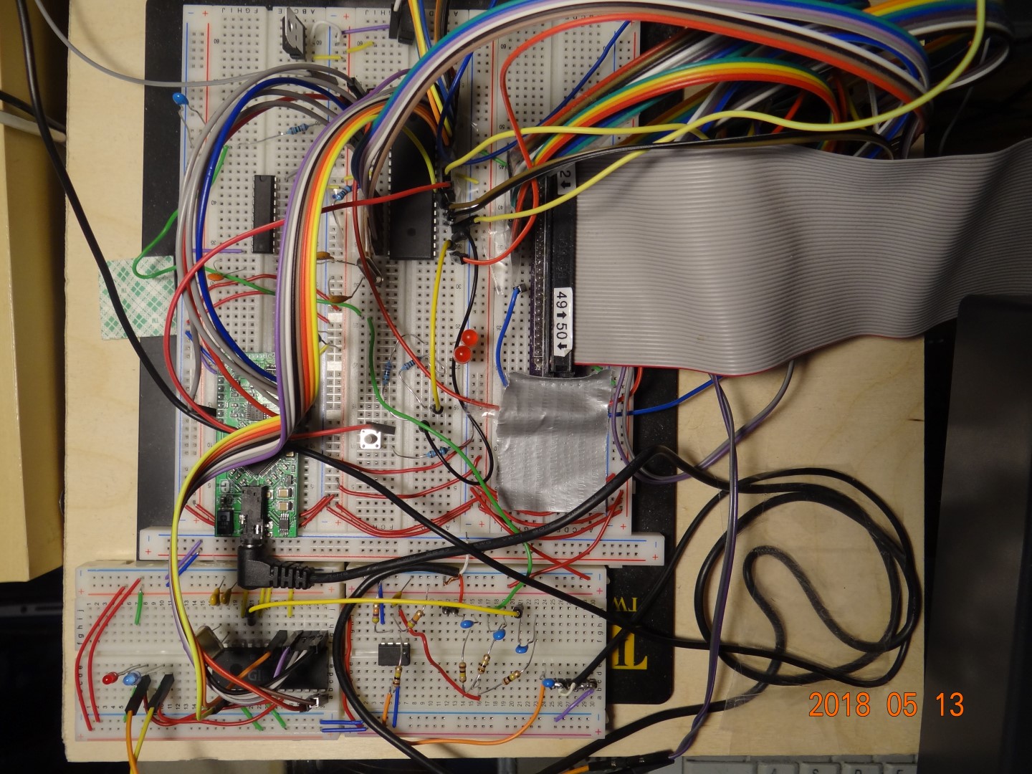
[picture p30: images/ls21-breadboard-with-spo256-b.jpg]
LambdaSpeak 2,1 Breadboard Prototype with SPO256-AL2


The schematics are not given here, but take a look at the [pin allocations for the Xilinx CPLD](firmware/ls21/xilinxXC9572XL/Main.ucf) and the [pin assignments for the ATmega](firmware/atmega644/ls21-with-spo256-al2/ls21-pins.h), from which the schematics can be deduced easily (also take a look at the LambdaSpeak 1.99 schematics for SPO256-AL2 wiring).   

The [ATmega 644 firmware](firmware/atmega644/ls21-with-spo256-al2/lambdaspeak21.hex) differs from the LambdaSpeak 1.95 / LambdaSpeak 2.0 firmware, as it needs to drive / control the additional SPO256-AL2. 

### The LambdaSpeak Firmware 

#### Firmware for LambdaSpeak 1.95 - GAL22V10 & ATmega 644  

The GAL22V10 firmware was designed using WinCUPL. I have successfully used GAL22V10-B's and GAL22-V10-D's. 

I recommend the [Genius G540 USB Universal Programmer](https://www.amazon.com/gp/product/B075TGDDJM) for GAL22V10 programming. The [Signstek TL866CS Universal USB MiniPro EEPROM FLASH BIOS Programmer](https://www.amazon.com/gp/product/B00K73TSLM) failed on most of my GAL22V10B's, and worked fine on GAL22B10D's.  

For ATmega programming, I am using USBTinyISP, and a standard [ATmega programming board](https://www.ebay.com/itm/AVR-ATMEGA16-Minimum-System-Board-ATmega32-USB-ISP-USBasp-Programmer-F-ATMEL-S/352106489534). 

I have programmed the ATmega [using avrdude with these settings](firmware/atmega644/avr-flash.txt) (notice the fuses).

Firmware files: 

* [GAL22V10 Address Decoder JED File (U1)](firmware/ls195/gal22v10/ls195-address-decoder-U1.jed)
* [ATmega 644 Firmware (U4)](firmware/atmega644/ls195-and-ls20/ls195-ls20-firmware.hex)

#### Firmware for LambdaSpeak 1.99 - 2x GAL22V10 & ATmega 644  

Same comments as for the 1.95 version apply. 

Firmware files: 

* [GAL22V10 Address Decoder JED File (U1)](firmware/ls199/gal22v10/ls199-address-decoder-U1.jed)
* [GAL22V10 Databus Multiplexer JED File (U3)](firmware/ls199/gal22v10/ls199-databus-multiplexer-U3.jed)
* [ATmega 644 Firmware (U4)](firmware/atmega644/ls199-and-ls21-with-spo256-al2/ls199-ls21-firmware.hex)
 
#### Firmware for LambdaSpeak 2.0 - Xilinx XC9572XL & ATmega 644  

The CPLD firmware was designed using **Xilinx' ISE WebPACK** design software, in **Verilog**. The CPLD was programmed using a QFP-64 test socket, connected via JTAG pins to the standard  Xilinx USB platform cable.

Regarding ATmega programming, same comments as already made apply.  

Firmware files: 

* [XC9572XL JED file](firmware/ls20/xilinxXC9572XL/Main.jed) 
* [Verilog file of XC9572XL JED file](firmware/ls20/xilinxXC9572XL/lambdaspeak2.v) 
* [ATmega 644 Firmware - identical with LS 1.95 version](firmware/atmega644/ls195-and-ls20/ls195-ls20-firmware.hex)

#### Firmware for LambdaSpeak 2.1 - Xilinx XC9572XL & ATmega 644 

Same comments as for LambdaSpeak 2.0 apply. 

Firmware files: 

* [XC9572XL JED file](firmware/ls21/xilinxXC9572XL/Main.jed) 
* [Verilog file of XC9572XL JED file](firmware/ls21/xilinxXC9572XL/lambdaspeak2.v) 
* [ATmega 644 Firmware - identical with LS 1.99 version](firmware/atmega644/ls199-and-ls21-with-spo256-al2/ls199-ls21-firmware.hex)

Notice that the LS 2.1 CPLD firmware differs from the LS 2.0 CPLD firmware, as it provides for the additional control lines required for driving the SPO256-AL2 etc.  

### Detailed Description of the ATmega LambdaSpeak Firmware 

The **current version** of the unified LambdaSpeak ATmega firmware is **7**. The highest firmware version will be 15. The unified ATmega LambdaSpeak firmware supports LambdaSpeak 1.5 (obsolete), LambdaSpeak 1.8 (obsolete), LambdaSpeak 1.95 (current), LambdaSpeak 1.99 with  additional optional SPPO256-AL2 (current), LambdaSpeak 2.0 (future SMD PCB), and LambdaSpeak 2.1 with additional optional SPO256-AL2 (future SMD PCB). 

LambdaSpeak listens to the CPC's IO ports &FBEE and &FAEE (in SSA-1 mode),  to &FBFE (in DK'tronics modes), as well as to &FFxx in Amdrum mode (and only then). The native DECtalk and native Epson modes are also using IO port &FBEE. 
 
The LambdaSpeak 1.95 and LambdaSpeak 2.1 hardware uses a single signal for address decoding from the GAL22V10 (resp. Xilinx CPLD) to the ATmega 644, so in fact, the LambdaSpeak firmware cannot distinguish whether a request was made for &FBEE, &FAEE, &FBFE, or &FFxx. However, &FFxx is only decoded in Amdrum mode (a signal is given to the GAL from the ATmega in order to en/disable &FFxx decoding). For the other modes, the current mode of LambdaSpeak determines how LambdaSpeak reacts to the IO request at &FBEE, &FAEE, or &FBFE, respectively. Even though these addresses are decoded "in parallel", the LambdaSpeak RSX Driver by TFM, the SSA-1 driver software, and the DK'tronics driver software are not getting confused, because their protocols are different (in fact, all these driver software can be used in parallel). 

ASCII for speech is only 7 Bit. Hence, every byte with the 8th bit being set is considered a **control byte** and used for controlling LambdaSpeak, for setting the current mode, changing the current voice,  volume and speech rate, etc.  

Many of these modes are demonstrated in the BASIC program `demo01.bas` found on the [`LS195.dsk` disk](cpc/lambda/LS195.dsk). 

The following Control Bytes are understood by the firmware version 7: 

- &FF: reset LambdaSpeak. Only works if LambdaSpeak is not in PCM test mode, or in Amdrum mode. Even the reset button of LambdaSpeak will be ineffective during PCM sample playing (interrupts are disabled during PCM sample playing in order to maximize audio sample quality).  Reset puts LambdaSpeak into default configuration.  The **default mode** is the **SSA-1 emulation mode**. 

The **first group of control bytes** determines the **mode** of LambdaSpeak: 

- &EF: native LambdaSpeak / Epson mode. This is the simplest mode. In this mode, simply send a series of ASCII characters to IO port &FBFE, terminated by CR (13), to make it speak the string. In Epson mode, LambdaSpeak uses the **value 32 on port &FBFE to signal that it is ready to accept the next byte.** Voice, pitch, volume, and speech rate (words per minute) can be changed, see below. By default, a so-called **blocking mode** of operation is used for the native Epson mode. In **blocking mode**, the Z80 CPU / the CPC is **halted** while LambdaSpeak is speaking. This is achieved by pulling down the Z80 READY signal available on the expansion port. Control returns to the CPC when the speech has finished. However, in order to cancel / interrupt the speech, LambdaSpeak also offers a **non-blocking mode** of operation, in which the Z80 is not halted while LambdaSpeak is speaking. Hence, while LambdaSpeak is speaking, a **stop** control byte can be sent to LambdaSpeak from the CPC, and LambdaSpeak will stop speaking immediately. Notice that sending the **stop** control byte (byte &DF) is **the only operation that is supported in non-blocking mode while LambdaSpeak is speaking**. Being able to abort the currently ongoing speech is the sole purpose of the non-blocking mode. 

- &EE: native DECTalk mode of LambdaSpeak. This mode is more involved than the Epson mode, as the DECTalk syntax allows phoneme-based control of speech synthesis. Check out the DECTalk manual and have a look at `demo01.bas`. In DECTalk mode, LambdaSpeak uses the **value 32 on port &FBEE to signal that it is ready to accept the next byte.** Check out the DECTalk manual to learn about the more involved and powerful DECTalk syntax. As for the Epson mode, DECTalk mode supports a blocking and a non-blocking mode of operation, see above for explanation. 

- &ED: Amstrad SSA-1 emulation mode. A 90% compatible emulation of the SSA-1 speech synthesizer; check out games like "Roland in Space" or the SSA-1 driver software supplied in this repository. The ports are **&FBEE and &FAEE**, and the ready signal(s) of the SSA-1 are emulated accordingly. The emulation is faithful enough for games and the SSA-1 driver software to work well. It was tested with the SSA-1 driver software, and the games "Tubaruba", "Alex Higgins' World Pool", "Roland in Space", and a couple more, and worked flawlessly. Since the timing is not 100% accurate / faithful to the original hardware, I do not guarantee 100% compatibility. Check out the YouTube videos above to get an idea about SSA-1 emulation and compatibility. 
  - Please note that the SSA-1 mode **always works asynchronously** and that the CPC / Z80 CPU will never be paused. Rather, phonemes are being  buffered, and when the buffer is full (it has a capacity of 380 bytes), or when no phoneme has arrived for a couple of milliseconds (the flush delay time is configurable, see below), the buffer is flushed and spoken. Hence, **blocking and non-blocking mode** does not apply to the SSA-1 mode. 

- &EC: DK'tronics speech synthesizer emulation mode. A 90% emulation of the DK'tronics speech synthesizer. Same comments as for the SSA-1 emulation apply. DK'tronics uses the port **&FBFE**, and the ready signal is a bit simpler than in the SSA-1 case (only one bit is used); the signal is emulated accordingly. The speech synthesizer was tested with the DK'tronics ROM software, the DK'tronics speech synthesizer cassette software, and some old BASIC programs that were written for the DK'tronics (e.g., see `elisa.bas` on the `LS195.dsk`). Some games were tested as well, including "Jump Jet", "Alex Higgins' Pool", etc. Check out the YouTube videos to get an idea about DK'tronics emulation and compatibility. 
  - The same comments regarding phoneme buffer and blocking and non-blocking mode as for the SSA-1 mode apply to the DK'tronics mode. Same thing. 

- &EB: enable non-blocking mode for native Epson and native DECTalk mode of LambdaSpeak. Explained above, see there. Does not apply to SSA-1 and DK'tronics mode. 

- &EA: enable blocking mode for native Epson and native DECTalk mode. See explanation above. Does not apply to SSA-1 and DK'tronics mode. 

- &E9: by default, LambdaSpeak confirms all control bytes and changes to configuration by voice. This enable these audible voice confirmations. 

- &E8: puts LambdaSpeak into a less verbose / silent mode, where it does not confirm changes to configuration and modes. Of course, it will still speak in this mode, but no longer confirms control bytes audibly by voice. 

- &E7: the DECTalk / Epson firmware supports Spanish and English text-to-speech synthesis. This enables the English mode. This is the default for LambdaSpeak. Does not apply to DK'tronics or SSA-1 mode; for these, no text-to-speech conversion takes place, as this is handled in the SSA-1 or DK'tronics driver software. The driver software performs a text-to-phoneme translation, and phonemes are being sent to LambdaSpeak. These get mapped to DECTalk phonemes then. 

- &E6: Spanish language mode. Not really tested, but should work. 

- &E5: enables the **fast getters mode**. The firmware offers a couple of "getter" methods / control bytes which can be used to query / acquire the current settings of LambdaSpeak, e.g., the current volume, current voice, etc. These "getter" methods / control bytes follow a certain "data transmission" protocol. If a getter is invoked, LambdaSpeak first puts a zero-byte on the Z80 / CPC data bus (note that all LambdaSpeak modes use a non-zero "ready" signal on the data bus, so ready cannot be confused with zero), then it waits for 50 microseconds, next puts the requested data 4bit value (e.g., the current volume) on the data bus for 50 microseconds, and then puts another zero-byte on the databus for 50 microseconds, before returning to normal LambdaSpeak operation (i.e., the **ready signal** of the corresponding mode is given on the databus). Notice that the zero-byte is reserved for this synchronization purpose, and the "getter" methods / control bytes will never return a zero value (i.e., there is no zero volume, no voice number zero, etc.) Hence, a program reading these values can check for these "zero-padded 4bit values". Using &E5, the described time delays are short, i.e., 50 microseconds, suitable for machine code programs that want to read the LambdaSpeak settings. 

- &E4: using the **slow getters mode**, the requested setting value is much longer visible on the databus, i.e., for 50 milliseconds (compared to the 50 microseconds in **fast getters mode**). This mode is suitable for (slower) BASIC programs that want to read the LambdaSpeak settings.   

- &E3: LambdaSpeak offers a PCM sample-playing mode - it emulates the **Amdrum module**. In this mode, every byte sent to port &FFxx (xx = arbitrary) will immediately be played as an 8bit PCM sample. The **Amdrum software** works out of the box in this mode, and sample quality is surprisingly good / high, given that no DAC chip is used, but the PCM conversion is implemented in software on the ATmega 644, using a fast timer. This mode can only be exited by power cycling LambdaSpeak. All ATmega interrupts are disabled, for maximum processing speed and sample quality. Hence, even the reset button of LambdaSpeak is ineffective. Decoding of IO addresses &FFxx will only be active when the Amdrum mode is enabled (the ATmega enables a control signal / line to the GAL22V10 address decoder or Xilinx CPLD, respectively). 

- &E2: **only LambdaSpeak 2.1 with SPO256-AL2** - authentic SSA-1 re-implementation using the original SPO256-AL2 speech chip from General Instruments. This mode is 100% authentic and compatible to the original. This mode works synchronously, allophones are uttered immediately, no buffering takes place, just as in the original. 

- &E1: **only LambdaSpeak 2.1 with SPO256-AL2** - authentic DK'tronics re-implementation using the original SPO256-AL2 speech chip from General Instruments. This mode is 100% authentic and compatible to the original. (A slight difference is the lower pitch - the DK'tronics speech synthesizer used the 4 MHz clock signal from the CPC instead of a recommended 3.1 MHz clock for the SPO256-AL2. Hence, the pitch is a bit lower, and the generated speech is a bit clearer IMHO.)  This mode works synchronously, allophones are uttered immediately, no buffering takes place, just as in the original. 

- &DF: in non-blocking native Epson (or native DECTalk) mode, **speech can be stopped immediately by sending this control byte**. This is the only control byte which can be processed in non-blocking mode while LambdaSpeak is speaking. The sole purpose of the non-blocking mode is to allow the sending of this stop byte and such that speech can be stopped / interrupted at any time in this mode. 

- &DE: in SSA-1 or DK'tronics mode, a phoneme buffer is used. The buffer is flushed when no new phoneme has arrived for a certain amount of time, or when the buffer is full. The buffer can also be flushed at any time by sending this control byte. 

The **next group of control bytes** is used for getting info, and reading settings (so-called "getter" methods / "getter control bytes"). The getter methods return 4bit values, and the upper 4bits of the databus are being used (upper nibble, bits 4, 5, 6, and 7). There is never a zero value being returned. The zero-byte is used for synchronization instead, as "padding byte", as explained above.  Notice that the returned value will be available on the databus for either 50 microseconds (in "fast getters" mode), or for 50 milliseconds (in "slow getters" mode). Before and after, a zero-byte is sent. 

- &CF: returns the current mode. This is a 4bit vector, using the upper 4 bits. Bits 4 and 5 indicate the current mode (native Epson, native DECTalk, SSA-1, DKtronics, from 0 to 3), bit 6 is on if blocking mode is enable, and off otherwise; and bit 7 is off for English mode, and on for Spanish mode.

- &CE: returns the current volume. 

- &CD: returns the current voice. The voices 1 to 8 are pre-defined. 

- &CC: returns the current speak rate. 

- &CB: returns the current language. 

- &CA: returns the current flush buffer delay time, in milliseconds.  

- &C9: returns the current firmware version number (currently, 7). 

- &C8: speaks a copyright note.

- &C7: get a quote from HAL 9000! 

- &C6: sing "Daisy Bell", a classic DECTalk song. 

- &C5: an echo test program to check IO port communication. In this mode, every byte sent to port &FBEE and &FAEE is immediately "echoed" back onto the databus, such that it can be read and compared with the byte that was sent. The sent and returned byte should be identical, of course. This mode can only be exited by pushing the LambdaSpeak reset button, or by power cycling of course. 

- &C4: like &C5, but for port &FBFE. 

- &C3: speak a test message. Useful for testing different voices and speech parameters (speech rate, etc.)

- &C2: PCM sample test. Play a sample from HAL 9000 - "I'm completely operational", using the Amdrum PCM output. Use LambdaSpeak's reset button to exit this mode.  

- &B0: set current voice to the default voice. 

- &B1 - &BF: set current voice to voice 1 (&B1) to 15 (&BF). 

- &A0: set current volume to the default volume. 

- &A1 - &AF: set current volume to volume level 1 (&A1) to volume level 15 (&AF). 

- &90: set current speak rate to default speak rate. 

- &91 - &9F: set current speak rate to rate level 1 (&91) to rate level 15 (&9F). 

- &80: set flush buffer delay time to default time. 

- &81 - &8F: set current flush buffer delay time to delay time 1 (&81) to delay time 15 (&8F). 

#### Overview Table of Control Bytes   
     
      case 0xFF : process_reset(); break; 
    
      case 0xEF : native_mode_epson(); break; 
      case 0xEE : native_mode_dectalk(); break; 
      case 0xED : ssa1_mode(); break; 
      case 0xEC : dktronics_mode(); break; 
      case 0xEB : non_blocking(); break; 
      case 0xEA : blocking(); break; 
      case 0xE9 : confirmations_on(); break;  
      case 0xE8 : confirmations_off(); break;   
      case 0xE7 : english(); break; 
      case 0xE6 : spanish(); break; 
      case 0xE5 : fast_getters(); break; 
      case 0xE4 : slow_getters(); break; 
      case 0xE3 : amdrum_mode(); break; 
      case 0xE2 : spo256_ssa1_mode(); break; 
      case 0xE1 : spo256_dktronics_mode(); break; 
    
      case 0xDF : stop_command(); break;  
      case 0xDE : flush_command(); break;
     
      case 0xCF : get_mode(); break; 
      case 0xCE : get_volume(); break; 
      case 0xCD : get_voice(); break; 
      case 0xCC : get_rate(); break; 
      case 0xCB : get_language(); break; 
      case 0xCA : get_delay(); break; 
      case 0xC9 : get_version(); break; 
      case 0xC8 : speak_copyright_note(); break; 
      case 0xC7 : speak_hal9000_quote(); break; 
      case 0xC6 : sing_daisy(); break; 
      case 0xC5 : echo_test_program(); break; 
      case 0xC4 : echo_test_program_dk(); break; 
      case 0xC3 : test_message(); break; 
      case 0xC2 : pcm_test(); break; 
    
      case 0xB0 : set_voice_default(); break;
      case 0xB1 : set_voice(1); break; // default
      case 0xB2 : set_voice(2); break;
      case 0xB3 : set_voice(3); break;
      case 0xB4 : set_voice(4); break;
      case 0xB5 : set_voice(5); break;
      case 0xB6 : set_voice(6); break;
      case 0xB7 : set_voice(7); break;
      case 0xB8 : set_voice(8); break;
      case 0xB9 : set_voice(9); break;
      case 0xBA : set_voice(10); break;
      case 0xBB : set_voice(11); break;
      case 0xBC : set_voice(12); break;
      case 0xBD : set_voice(13); break;
      case 0xBE : set_voice(14); break;
      case 0xBF : set_voice(15); break;
    
      case 0xA0 : set_volume_default(); break;
      case 0xA1 : set_volume(1); break;
      case 0xA2 : set_volume(2); break;
      case 0xA3 : set_volume(3); break;
      case 0xA4 : set_volume(4); break;
      case 0xA5 : set_volume(5); break;
      case 0xA6 : set_volume(6); break;
      case 0xA7 : set_volume(7); break;
      case 0xA8 : set_volume(8); break;
      case 0xA9 : set_volume(9); break;
      case 0xAA : set_volume(10); break;
      case 0xAB : set_volume(11); break;
      case 0xAC : set_volume(12); break;
      case 0xAD : set_volume(13); break;
      case 0xAE : set_volume(14); break; // default 
      case 0xAF : set_volume(15); break;
    
      case 0x90 : set_rate_default(); break;
      case 0x91 : set_rate(1); break;
      case 0x92 : set_rate(2); break;
      case 0x93 : set_rate(3); break;
      case 0x94 : set_rate(4); break;
      case 0x95 : set_rate(5); break;
      case 0x96 : set_rate(6); break;
      case 0x97 : set_rate(7); break;
      case 0x98 : set_rate(8); break;
      case 0x99 : set_rate(9); break;
      case 0x9A : set_rate(10); break;
      case 0x9B : set_rate(11); break;
      case 0x9C : set_rate(12); break; // default
      case 0x9D : set_rate(13); break;
      case 0x9E : set_rate(14); break;
      case 0x9F : set_rate(15); break;
    
      case 0x80 : set_buffer_delay_default(); break;
      case 0x81 : set_buffer_delay(1); break;
      case 0x82 : set_buffer_delay(2); break;
      case 0x83 : set_buffer_delay(3); break;
      case 0x84 : set_buffer_delay(4); break;
      case 0x85 : set_buffer_delay(5); break;
      case 0x86 : set_buffer_delay(6); break;
      case 0x87 : set_buffer_delay(7); break;
      case 0x88 : set_buffer_delay(8); break;
      case 0x89 : set_buffer_delay(9); break;
      case 0x8A : set_buffer_delay(10); break; // default !!
      case 0x8B : set_buffer_delay(11); break;
      case 0x8C : set_buffer_delay(12); break;
      case 0x8D : set_buffer_delay(13); break;
      case 0x8E : set_buffer_delay(14); break;
      case 0x8F : set_buffer_delay(15); break;    

### LambdaSpeak CPC BASIC Programming and |RSX Driver by TFM  

Here is the `demo01.bas` BASIC program (can also be found on the [`LS195.dsk` disk](cpc/lambda/LS195.dsk)) that illustrates LambdaSpeak use and programming, how to use native Epson and native DECTalk mode. The latter uses a fragment of the DECTalk "Happy Birthday" song found online. The program also shows how to change the current voice, how to use the "getter" commands to retrieve / read the current LambdaSpeak settings for voice and volume etc., and how to interrupt / abort ongoing speech whilst in non-blocking mode. 
    
    10 OUT &FBEE,&FF
    20 a=INP(&FBEE):IF a<>128 GOTO 20
    30 PRINT "hit space bar for quiet"
    40 OUT &FBEE,&EF
    50 WAIT &FBEE,32
    60 OUT &FBEE,&EB
    70 WAIT &FBEE,32
    80 a$="hello how are you i am lambdaspeak 123456789"
    90 FOR i=1 TO LEN(a$)
    100 c$=MID$(a$,i,1) 
    110 OUT &FBEE,ASC(c$)
    120 NEXT
    130 OUT &FBEE,13
    140 a=INP(&FBEE)
    150 IF INKEY$=" " THEN OUT &FBEE,&DF:PRINT "quiet!"
    160 IF a<>32 GOTO 140
    170 REM
    180 OUT &FBEE,&EE
    190 a$="[:phone arpa speak on][:rate 200][:n1][hxae<300,10>piy<300,10> brr<600,22>th<100>dey<600,19>dih<600,15>rdeh<600,14>ktao<600,12>k_<120>_<120>][:n1]"
    200 a$=a$+"[:phone arpa speak on][:rate 200][:n3][hxae<300,10>piy<300,10> brr<600,22>th<100>dey_<120>_<120>][:n3]"
    210 FOR i=1 TO LEN(a$)
    220 c$=MID$(a$,i,1)
    230 OUT &FBEE,ASC(c$)
    240 NEXT
    250 OUT &FBEE,13
    260 a=INP(&FBEE)
    270 IF INKEY$=" " THEN OUT &FBEE,&DF:PRINT "quiet!"
    280 IF a<>32 GOTO 260
    290 REM
    300 OUT &FBEE,&CE
    310 WAIT &FBEE,255
    320 PRINT INP(&FBEE)/16
    330 a=INP(&FBEE):IF a<>0 THEN GOTO 330
    340 WAIT &FBEE,32
    350 OUT &FBEE,&CC
    360 WAIT &FBEE,255
    370 PRINT INP(&FBEE)/16
    380 a=INP(&FBEE):IF a<>0 THEN GOTO 380
    390 WAIT &FBEE,32
    400 OUT &FBEE,&B2
    410 WAIT &FBEE,32
    420 OUT &FBEE,&CD
    430 WAIT &FBEE,255
    440 PRINT INP(&FBEE)/16
    450 a=INP(&FBEE):IF a<>0 THEN GOTO 450
    460 WAIT &FBEE,32
    470 OUT &FBEE,&CD
    
#### LambdaSpeak |RSX Driver and ROM by Dr. Stefan Stumpferl (aka TFM, Gunhed)

[TFM](http://futureos.cpc-live.com/pics/tfm_gr.jpg), well-known in the CPC Community for his [FutureOS operating system for the CPC](http://futureos.cpc-live.com/), has created an awesome |RSX driver for LambdaSpeak. It comes in two versions - as a ROM, and as a disc-based relocatable driver (loadable from BASIC). |RSX commands exists for all LambdaSpeak control bytes, and also some high-level functions are offered that do not directly correspond to LambdaSpeak control bytes. For example, a PCM sample `|play` command (and `|eplay` for playing from an extended memory extension) for LambdaSpeak's Amdrum mode is offered, as well as a `|speakscreen` screen reading and a `|speakfile` file reading function. 

The disc version of the software is shown in the following picture:  

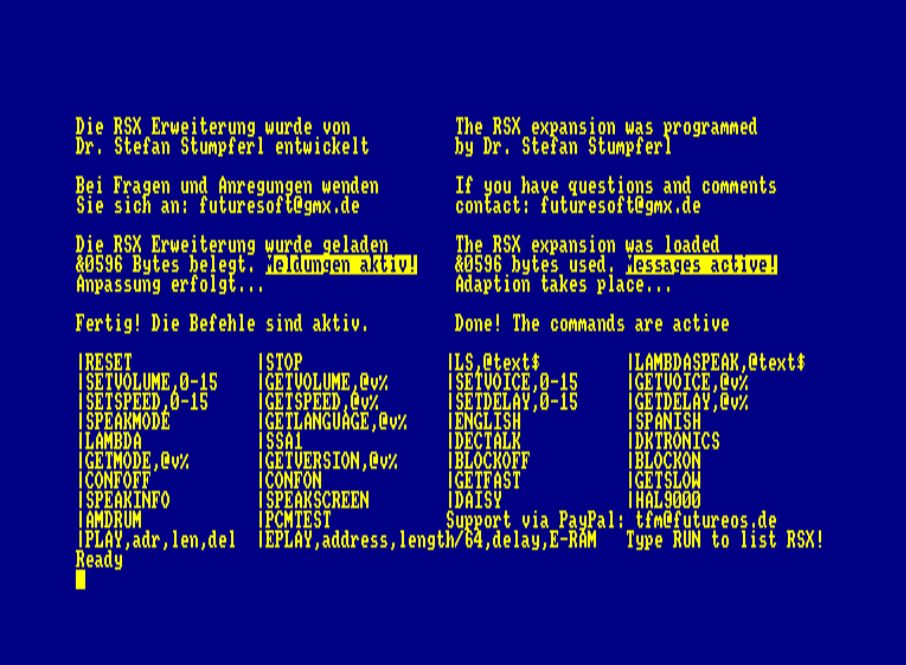
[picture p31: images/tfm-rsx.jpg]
TFM's LambdaSpeak RSX Driver


Here is a picture of the LambdaSpeak ROM, `|lshelp` command: 

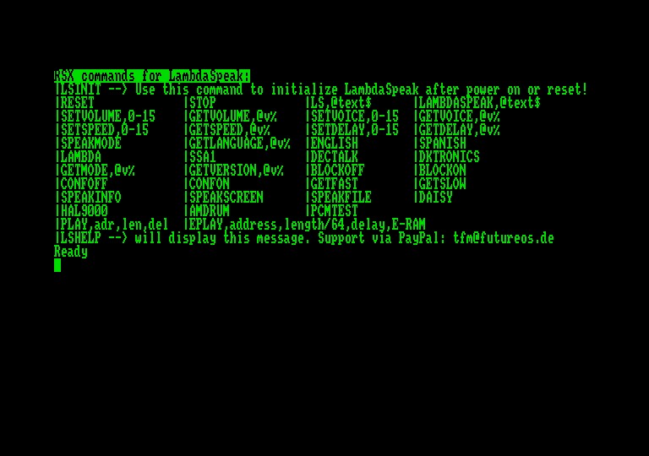
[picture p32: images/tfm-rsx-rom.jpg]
TFM's LambdaSpeak RSX ROM


The latest version of the [LambdaSpeak driver software is hosted on TFM's home page](http://futureos.cpc-live.com/files/LambdaSpeak_RSX_by_TFM.zip). The zip file also contains a `README` and the `.dsk` file contains an extensive manual describing all features of the software. 

### Maker Support 

For 79.79 $ you can purchase a fully assembled, complete LambdaSpeak 1.95. This price includes free shipping from the US to Europe, and also the Text2Speech click! daughter board. 

Please contact me via email if you are interested.  

### Acknowledgements

Thanks to [Teodor Costachioiuo](https://electronza.com/about-me/) for
the [Talking Clock Tutorial with the Mikroelektronika Text to Speech
Clock
Board](https://electronza.com/wp-content/uploads/2017/09/talking_clock-1.zip);
I have rewritten this (Arduino) code and ported it to WinAVR.

Bryce, for some technical discussions, and for suggesting to use a
Xilinx CPLD (I later switched back to GALs though).

Elliot Williams for his book "Make: AVR Programming" and [corresponding sources /AVR Programming Libraries.](https://github.com/hexagon5un/AVR-Programming).

Special thanks go to "zhulien" from the CPC Wiki Forum for suggesting to implement the Amdrum mode! Without him, this mode would not exist (I didn't even know about the Amdrum module) 

### Disclaimer 

Use at your own risk. I am not responsible for any potential damage you might cause to your CPC, other machinery, or yourself, in the process of assembling and using this piece of hardware.

**Enjoy!**

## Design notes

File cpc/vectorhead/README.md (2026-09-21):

# The Vector Head

A wireframe head digitized by hand off a P.M. Computerheft article in 1985,
rewritten in Z80 assembler, animated, and given a voice through the SP0256-AL2.

- `head.dsk` - for an emulator, or a real drive
- `head.hfe` - the same disc, for a Gotek or HxC

## Running it

You need a CPC with a disc drive and an **Amstrad SSA-1**, or **LambdaSpeak**
in SSA-1 mode. Then:

```
RUN"VH
```

**`RUN"VH`, not `RUN"HEAD`.** `VH.BAS` is what loads the letter-to-sound engine
that the typed-text speech needs; started any other way there is no prompt and
only the one sentence built into the program can be spoken. The program says so
on screen if that happens.

The head draws in about a fifth of a second. It introduces itself, and then you
can type any sentence - up to 96 characters - and have it spoken, with the lips,
the jaw, the chin and the eyes moving on the allophones. The allophones the
rules chose are listed under what you typed.

- `,` and `.` on their own change the speech rate (slow / medium / quick)
- `QUIT` on its own leaves

In an emulator:

```
mame cpc6128 -flop1 head.dsk -autoboot_delay 3 -autoboot_command 'RUN"VH\n'
```

The source is not public yet.

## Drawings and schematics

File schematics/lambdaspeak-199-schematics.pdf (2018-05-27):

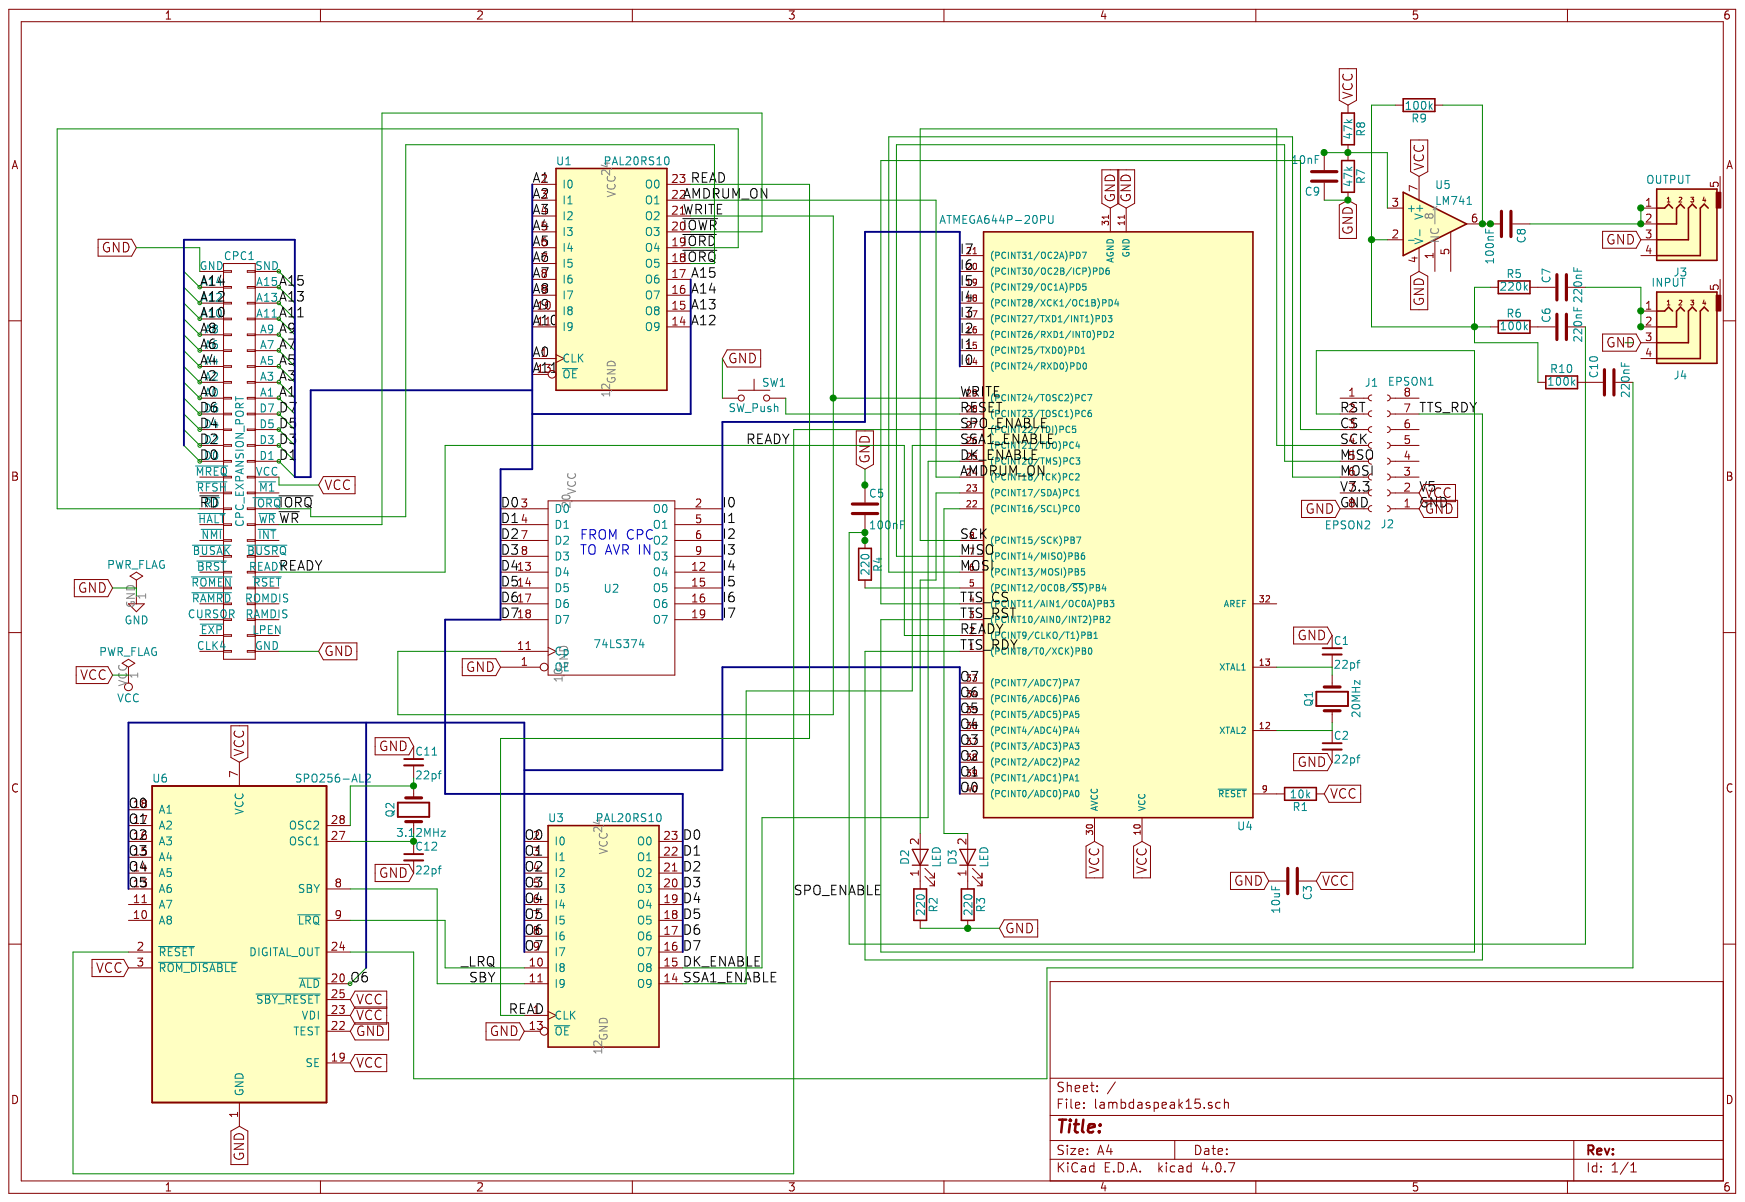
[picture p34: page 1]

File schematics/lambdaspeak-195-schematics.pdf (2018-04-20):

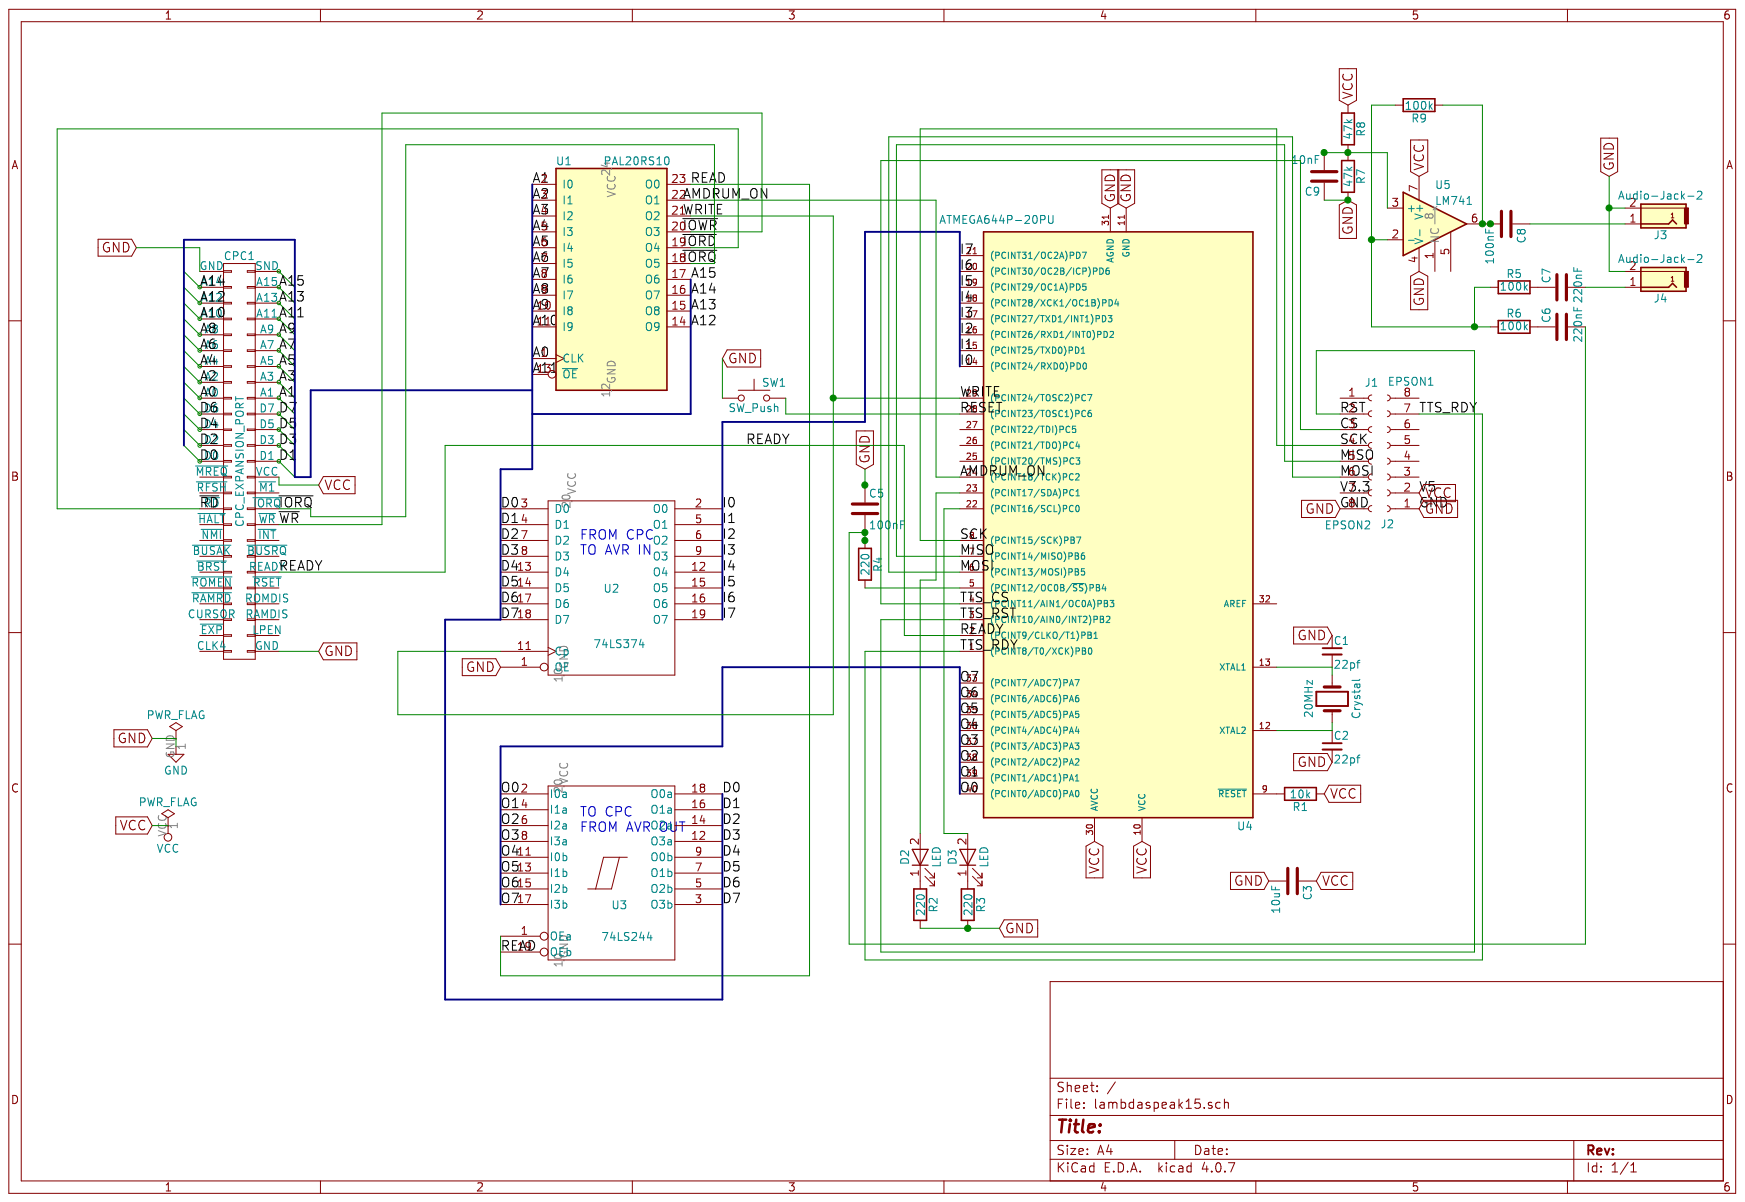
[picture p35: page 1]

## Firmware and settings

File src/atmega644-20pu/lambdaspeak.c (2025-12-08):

/* 
   LambdaSpeak - A Next-Generation Speech Synthesizer for the CPC 
   Firmware for LambdaSpeak 1.95, LambdaSpeak 1.99, and LambdaSpeak 3 
   Copyright (C) 2017 - 2019 Michael Wessel 

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
*/ 

//
// LambdaSpeak 1.95, LambdaSpeak 1.99, LambdaSpeak 3 
// Version 54
// License: GPL 3 
// 
// (C) 2019 Michael Wessel 
// (C) 2025 Michael Wessel (Spectrum Version)
// mailto:miacwess@gmail.com
// https://www.michael-wessel.info
// 

/*
  IMPORTANT LICENSE INFORMATION: 
  LambdaSpeak uses GPL 3. 
  This code uses the Epson S1V30120 firmware image from the TextToSpeech 
  click board library from MikroElektronika released under GPL2: 
  https://github.com/MikroElektronika/Click_TextToSpeech_S1V30120/blob/master/library/include/text_to_speech_img.h
  By using this code, you are also bound to the Epson license terms for the S1V30120 firmware:
  https://global.epson.com/products_and_drivers/semicon/products/speech/voice/sla/s1v30120_init_data.html
*/ 

#include "25LC1024.h" 

#include <avr/pgmspace.h>
#include <avr/io.h>

#include <util/delay.h>
#include <util/atomic.h>
#include <avr/interrupt.h>
#include <stdio.h> 
#include <stdlib.h> 
#include <avr/wdt.h>
#include <string.h>

#include "S1V30120_defines.h" 
#include "text_to_speech_img.h"

// #define CPC_READ_DELAY  FAST_CPC_GETTERS ? _delay_us(150) :  _delay_ms(10) 
// static volatile uint8_t FAST_GETTER_DELAY_US = 150; 
// static volatile uint8_t SLOW_GETTER_DELAY_MS = 10; 

static inline void delay_us(unsigned int microseconds) __attribute__((always_inline));
void delay_us(unsigned int microseconds)
{
  __asm__ volatile (
		    "1: push r22"     "\n\t"
		    "   ldi  r22, 4"  "\n\t"
		    "2: dec  r22"     "\n\t"
		    "   brne 2b"      "\n\t"
		    "   pop  r22"     "\n\t"
		    "   sbiw %0, 1"   "\n\t"
		    "   brne 1b"
		    : "=w" ( microseconds )
		    : "0" ( microseconds )
		    );
}




#define FAST_GETTER_DELAY_US 10
#define MEDIUM_GETTER_DELAY_US 50
#define SLOW_GETTER_DELAY_MS 20

#define CPC_READ_DELAY if ( FAST_CPC_GETTERS == 1 ) _delay_us(FAST_GETTER_DELAY_US); else if ( FAST_CPC_GETTERS == 2 ) _delay_us(MEDIUM_GETTER_DELAY_US); else _delay_ms(SLOW_GETTER_DELAY_MS) 

#define _NOP() do { __asm__ __volatile__ ("nop"); } while (0)
// used for a very short delay

#define BOOTMESSAGE
#define RTC
 
#define VERSION 54

#define SPECCY

//#define LS195 
#define LS199 
// #define LS300 

#include "HAL9000_defines.h"    

// = LS195  
#ifdef LS195
#include "ls195hardware.h"
#include "pcm.h"
//#include "pcm-dummy.h"
#endif 

// = LS199  
#ifdef LS199
#include "ls199hardware.h"
#include "pcm.h"
#endif 

#ifdef LS300
#include "ls300hardware.h"
#include "pcm3.h"
//#include "pcm-dummy.h"
#endif 

//
// SPI EEPROM OPCODES
//

#define WREN  6
#define WRDI  4
#define RDSR  5
#define WRSR  1
#define READ  3
#define WRITE 2

//
//
//

#define configure_speak_buffer_timer  TCCR0A = 0; TCCR0B = 0; setBit(TCCR0A, WGM01); OCR0A = 0xF9; setBit(TIMSK0, OCIE0A)

#define start_timer emulated_ssa1_dktronics_ms_counter = 0; setBit(TCCR0B, CS02); setBit(TCCR0B, CS00)

#define stop_timer  TCCR0B &= ~(1 << CS02); TCCR0B &= ~(1 << CS00) 

//
// CPC Databus 
// 

static volatile uint8_t databus = 0; 
static volatile uint8_t databus1 = 0; 
static volatile uint8_t databus2 = 0; 


//
// Speech Buffer
// 
 
static char command_string[188];  // longest string in HAL quotes and copyright messages

// for all communication to Epson chip
// ALSO, for LS3, this is the USART BUFFER SIZE! 

//  #define SEND_BUFFER_SIZE 280

#define SEND_BUFFER_SIZE 268 // 256 + 8 extra bytes for headers

// for Input Buffering from CPC: 

#define SPEECH_BUFFER_SIZE 256 
#define SPEECH_BUFFER_FLUSH_AT 253 // - 3 of SPEECH_BUFFER_SIZE 

#define TOTAL_BUFFER_SIZE 524 // 268 + 256 

//
// Buffers 
// 

static volatile uint8_t length = 0; 
static volatile uint8_t buffer[SPEECH_BUFFER_SIZE] = { 0 }; 

static char rcvd_msg[20] = { 0 };
static char send_msg[SEND_BUFFER_SIZE] = { 0 };

//
//
//

static volatile uint8_t usart_ring_buffer = 0; 
static volatile uint16_t usart_input_buffer_index = 0; // receive input from USART

static volatile uint16_t from_cpc_input_buffer_index = 0;  // input from CPC to send to USART
static volatile uint16_t cpc_read_cursor = 0;  // reading USART received buffer from CPC 


//
// Flow Control 
// 

#ifdef SPECCY 
static volatile uint8_t BLOCKING = 0;  
#else
static volatile uint8_t BLOCKING = 1;  
#endif
static volatile uint8_t NON_BLOCK_CONFIRMATIONS = 0;  
static volatile uint8_t STOP_NOW = 0; 

#define WAIT_UNTIL_FINISHED { STOP_NOW = 0; while ( ! tts_parse_response(ISC_TTS_FINISHED_IND, 0x0000, 16)) {  if (  ! STOP_NOW && ( bit_is_set(IOREQ_PIN, IOREQ_WRITE) ||  bit_is_set(IOREQ_PIN, IOREQ_WRITE_DK)) && FROM_CPC_OUTPUT == 0xDF ) { STOP_NOW = 1; break; } } }

//
//
//

#ifdef RTC

static uint8_t rtc_seconds;
static uint8_t rtc_minutes;
static uint8_t rtc_hours;
static uint8_t rtc_month;
static uint8_t rtc_year; 
static uint8_t rtc_date;
static uint8_t rtc_weekday; 

static uint8_t rtc_msb_temp;

static uint8_t rtc_hours_dec;
static uint8_t rtc_mins_dec; 
static uint8_t rtc_secs_dec;
static uint8_t rtc_year_dec;
static uint8_t rtc_month_dec;
static uint8_t rtc_date_dec;
static uint8_t rtc_weekday_dec; 

#endif 


//
// Utilities 
// 

#define BV(bit) (1 << (bit))
#define toggleBit(byte, bit)  (byte ^= BV(bit))
#define setBit(byte, bit) (byte |= BV(bit)) 
#define clearBit(byte, bit) (byte &= ~BV(bit))

#ifndef LSBFIRST
#define LSBFIRST 0
#endif
#ifndef MSBFIRST
#define MSBFIRST 1
#endif

#define SPI_CLOCK_DIV4 0x00
#define SPI_CLOCK_DIV16 0x01
#define SPI_CLOCK_DIV64 0x02
#define SPI_CLOCK_DIV128 0x03
#define SPI_CLOCK_DIV2 0x04
#define SPI_CLOCK_DIV8 0x05
#define SPI_CLOCK_DIV32 0x06

#define SPI_MODE0 0x00
#define SPI_MODE1 0x04
#define SPI_MODE2 0x08
#define SPI_MODE3 0x0C // 00001100  

#define SPI_MODE_MASK 0x0C  // CPOL = bit 3, CPHA = bit 2 on SPCR
#define SPI_CLOCK_MASK 0x03  // SPR1 = bit 1, SPR0 = bit 0 on SPCR
#define SPI_2XCLOCK_MASK 0x01  // SPI2X = bit 0 on SPSR

//
//
// 

static volatile unsigned short TTS_DATA_IDX;

static volatile unsigned short msg_index;

static volatile unsigned short msg_len;
static volatile unsigned short txt_len;

//
// LambdaSpeak part 
// 

#define BV(bit) (1 << (bit))
#define toggleBit(byte, bit)  (byte ^= BV(bit))
#define setBit(byte, bit) (byte |= BV(bit))
#define clearBit(byte, bit) (byte &= ~BV(bit))

// 
//
// 

#define TRANSMIT_ON_ONLY   { setBit(LED_PORT_TRANSMIT, TRANSMIT_LED); clearBit(LED_PORT_READY, READY_LED); } 
#define READY_ON_ONLY      { setBit(LED_PORT_READY, READY_LED); clearBit(LED_PORT_TRANSMIT, TRANSMIT_LED); }  

#define TRANSMIT_ON   setBit(LED_PORT_TRANSMIT, TRANSMIT_LED) 
#define READY_ON      setBit(LED_PORT_READY, READY_LED) 

#define TRANSMIT_OFF  clearBit(LED_PORT_TRANSMIT, TRANSMIT_LED) 
#define READY_OFF     clearBit(LED_PORT_READY, READY_LED) 

#define LEDS_OFF { TRANSMIT_OFF; READY_OFF; }
#define LEDS_ON  { TRANSMIT_ON; READY_ON; }

//
//
//

#ifdef LS195 

#define SP0256_SSA1_ON  
#define SP0256_DK_ON    
#define SP0256_OFF      

#define EPSON_SSA1_ON  
#define EPSON_DK_ON    

#define LAMBDA_EPSON_ON 
#define LAMBDA_DECTALK_ON

#define EEPROM_PCM_UPLOAD_ON 
#define EEPROM_PCM_PLAY_ON  

#define SERIAL_ON  

#endif

//
//
//

#ifdef LS199 

#define SEND_TO_SP0        databus = 0b11000000 | databus ; DATA_TO_SP0(databus); _delay_us(2); databus &= 0b10111111; DATA_TO_SP0(databus) 

#define SEND_TO_SP02       databus &= 0b10111111; DATA_TO_SP0(databus); _delay_us(2); databus |= 0b11000000; DATA_TO_SP0(databus)

#define SP0256_GENERIC_ON  databus = 0b01000000; DATA_TO_SP0(databus); setBit(SP0256_ENABLE_PORT, SP0256_ENABLED); _delay_ms(20); databus = 0; SEND_TO_SP0 

#define SP0256_OFF         clearBit(SP0256_ENABLE_PORT, SP0256_ENABLED)

#define SP0256_SSA1_ON     clearBit(AMDRUM_PORT, AMDRUM_ENABLED); setBit(SP0256_ENABLE_PORT, SSA1_MODE); clearBit(SP0256_ENABLE_PORT, DK_MODE); SP0256_GENERIC_ON; databus = 0; SEND_TO_SP02 

#define SP0256_DK_ON       clearBit(AMDRUM_PORT, AMDRUM_ENABLED); setBit(SP0256_ENABLE_PORT, DK_MODE); clearBit(SP0256_ENABLE_PORT, SSA1_MODE); SP0256_GENERIC_ON; databus = 0; SEND_TO_SP02 


#define EPSON_SSA1_ON  
#define EPSON_DK_ON    

#define LAMBDA_EPSON_ON 
#define LAMBDA_DECTALK_ON

#define EEPROM_PCM_UPLOAD_ON 
#define EEPROM_PCM_PLAY_ON  

#define SERIAL_ON  
 
#endif
 
// 
//
//

#ifdef LS300 

// 9600 at 8N1  

static volatile uint32_t SERIAL_RATE = 0; 
static volatile uint8_t SERIAL_BAUDRATE = 2; 
static volatile uint8_t SERIAL_WIDTH = 8; 
static volatile uint8_t SERIAL_PARITY = 0; 
static volatile uint8_t SERIAL_STOP_BITS = 1; 


#define SEND_TO_SP0        databus = 0b11000000 | databus ; DATA_TO_SP0(databus); _delay_us(2); databus &= 0b10111111; DATA_TO_SP0(databus) 

#define SEND_TO_SP02       databus &= 0b10111111; DATA_TO_SP0(databus); _delay_us(2); databus |= 0b11000000; DATA_TO_SP0(databus)

#define SP0256_GENERIC_ON  databus = 0b01000000; DATA_TO_SP0(databus); setBit(SP0256_ENABLE_PORT, SP0256_ENABLED); _delay_ms(20); databus = 0; SEND_TO_SP0 

#define SP0256_OFF         clearBit(SP0256_ENABLE_PORT, SP0256_ENABLED)

#define SP0256_SSA1_ON     clearBit(AMDRUM_PORT, AMDRUM_ENABLED); setBit(SP0256_ENABLE_PORT, SSA1_MODE); clearBit(SP0256_ENABLE_PORT, DK_MODE); SP0256_GENERIC_ON; databus = 0; SEND_TO_SP02 

#define SP0256_DK_ON       clearBit(AMDRUM_PORT, AMDRUM_ENABLED); setBit(SP0256_ENABLE_PORT, DK_MODE); clearBit(SP0256_ENABLE_PORT, SSA1_MODE); SP0256_GENERIC_ON; databus = 0; SEND_TO_SP02 

#define EPSON_SSA1_ON      clearBit(SP0256_ENABLE_PORT, SP0256_ENABLED); setBit(AMDRUM_PORT, AMDRUM_ENABLED); setBit(SP0256_ENABLE_PORT, SSA1_MODE); clearBit(SP0256_ENABLE_PORT, DK_MODE) 

#define EPSON_DK_ON        clearBit(SP0256_ENABLE_PORT, SP0256_ENABLED); setBit(AMDRUM_PORT, AMDRUM_ENABLED); clearBit(SP0256_ENABLE_PORT, SSA1_MODE); setBit(SP0256_ENABLE_PORT, DK_MODE)

// those 2 have the same effect on hardware / CPLD side - DECTalk vs. Epson is only internal for Firmware Software, no Status LED or similar 
#define LAMBDA_EPSON_ON    clearBit(SP0256_ENABLE_PORT, SP0256_ENABLED); clearBit(AMDRUM_PORT, AMDRUM_ENABLED); clearBit(SP0256_ENABLE_PORT, SSA1_MODE); clearBit(SP0256_ENABLE_PORT, DK_MODE)

#define LAMBDA_DECTALK_ON  clearBit(SP0256_ENABLE_PORT, SP0256_ENABLED); setBit(AMDRUM_PORT, AMDRUM_ENABLED); setBit(SP0256_ENABLE_PORT, SSA1_MODE); setBit(SP0256_ENABLE_PORT, DK_MODE)

//#define EEPROM_PCM_UPLOAD_ON clearBit(SP0256_ENABLE_PORT, SP0256_ENABLED); clearBit(AMDRUM_PORT, AMDRUM_ENABLED); setBit(SP0256_ENABLE_PORT, SSA1_MODE); clearBit(SP0256_ENABLE_PORT, DK_MODE)

//#define EEPROM_PCM_PLAY_ON   clearBit(SP0256_ENABLE_PORT, SP0256_ENABLED); clearBit(AMDRUM_PORT, AMDRUM_ENABLED); clearBit(SP0256_ENABLE_PORT, SSA1_MODE); setBit(SP0256_ENABLE_PORT, DK_MODE) 

#define EEPROM_PCM_UPLOAD_ON clearBit(SP0256_ENABLE_PORT, SP0256_ENABLED); clearBit(AMDRUM_PORT, AMDRUM_ENABLED); clearBit(SP0256_ENABLE_PORT, SSA1_MODE); setBit(SP0256_ENABLE_PORT, DK_MODE)

#define EEPROM_PCM_PLAY_ON   setBit(SP0256_ENABLE_PORT, SP0256_ENABLED); setBit(AMDRUM_PORT, AMDRUM_ENABLED); setBit(SP0256_ENABLE_PORT, SSA1_MODE); clearBit(SP0256_ENABLE_PORT, DK_MODE) 

#define SERIAL_ON    clearBit(SP0256_ENABLE_PORT, SP0256_ENABLED); clearBit(AMDRUM_PORT, AMDRUM_ENABLED); setBit(SP0256_ENABLE_PORT, SSA1_MODE); setBit(SP0256_ENABLE_PORT, DK_MODE)


#endif

//
//
//

#define AMDRUM_ON SP0256_OFF; AMDRUM_PORT = 0; setBit(AMDRUM_PORT, AMDRUM_ENABLED) 

//
// Status   
// 
 
static volatile int FAST_CPC_GETTERS = 0;  // for CPC_READ_DELAY : 0 = BASIC / SLOW, 1 = MC / FAST, 2 = MEDIUM 

typedef enum { SSA1_M = 0, LAMBDA_EPSON_M = 1, LAMBDA_DECTALK_M = 2, DKTRONICS_M = 3, AMDRUM_M = 4, SSA1_SP0_M = 5,  DKTRONICS_SP0_M = 6,  EEPROM_PCM_UPLOAD_M = 7, EEPROM_PCM_PLAY_M = 8, SERIAL_M = 9, START_OVER_SAME_MODE = 10 } LS_MODE; 

#ifdef SPECCY 
static volatile LS_MODE CUR_MODE = LAMBDA_DECTALK_M; 
static volatile LS_MODE LAST_MODE = LAMBDA_DECTALK_M;  
#else
static volatile LS_MODE CUR_MODE = SSA1_M; 
static volatile LS_MODE LAST_MODE = SSA1_M;  
#endif

// 
//
//

#define VOLUME_DEFAULT 13
#define SPEAK_RATE_DEFAULT 9
#define FLUSH_BUFFER_DELAY_DEFAULT 10 

static volatile uint8_t VOICE = ISC_TTS_VOICE + 1; 
static volatile uint8_t SPEAK_RATE = SPEAK_RATE_DEFAULT; 
static volatile uint8_t LANGUAGE = ISC_TTS_LANGUAGE;  
static volatile uint8_t VOLUME = VOLUME_DEFAULT; 
static volatile uint8_t CONFIRM_COMMANDS = 1; 
static volatile uint8_t FLUSH_BUFFER_DELAY = FLUSH_BUFFER_DELAY_DEFAULT;  

//
// Buffer 
// 

#define SSA1_DKTRONICS_FLUSH_BUFFER_AFTER_MS 110 
#define SSA_DKTRONICS_LOADME_AGAIN_AFTER_MS 14

static volatile uint8_t emulated_ssa1_buffer_size = 0; 
static volatile uint8_t emulated_ssa1_dktronics_ms_counter = 0; 

//
//
// 

// static uint16_t allo_length[0x40]; 
static char*    allo_map[0x40]; 

//
//
// 

static volatile uint8_t ssa1_and_dk_flush_buffer_after_ms = SSA1_DKTRONICS_FLUSH_BUFFER_AFTER_MS;
static volatile uint8_t ssa_dktronics_loadme_again_after_ms = SSA_DKTRONICS_LOADME_AGAIN_AFTER_MS;


//
//
// 

inline static void setBitOrder(uint8_t bitOrder) {
  if (bitOrder == LSBFIRST) SPCR |= _BV(DORD);
  else SPCR &= ~(_BV(DORD));
}

inline static void setDataMode(uint8_t dataMode) {
  SPCR = (SPCR & ~SPI_MODE_MASK) | dataMode;
}
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
int main(void) {

  // uint8_t diag = MCUSR;

  MCUSR = 0;
  MCUSR = 0;

  wdt_init();  // soft reset init 

  // disable JTAG ! SET IT TWICE REALLY!!!
  MCUCR=0x80;// for the atmega644
  MCUCR=0x80;// for the atmega644

  //
  //
  //

  init_pins();  
  LEDS_OFF;

  //
  // diagnostics 
  //

  /* 
     if (bit_is_set(diag, JTRF)) {
     blink_led_slow(1);
     }

     if (bit_is_set(diag, WDRF)) {
     blink_led_slow(2);
     }
  
     if (bit_is_set(diag, BORF)) {
     blink_led_slow(3);
     }

     if (bit_is_set(diag, EXTRF)) {
     blink_led_slow(4);
     }

     if (bit_is_set(diag, EXTRF)) {
     blink_led_slow(5);
     }

     blink_led_fast(100); 
    
  */ 

  //
  //
  //

  init_reset_handler();   
  init_allophones();  

  blink_led_fast(20); 

  tts_setup(); 
  
  //
  //
  //

  SP0256_OFF;

  //
  //
  //

#ifdef BOOTMESSAGE  
  speech_ready_message(); 
#endif 
  tts_configure_dectalk();

  //
  //
  //

  /*
 
    uint8_t a = 250;
    uint8_t b = 5; 

    uint8_t diff = b - a;

    sprintf(command_string, "Result is %d ", diff);

    command_confirm(command_string); 

  */

  sei(); 

  //
  //
  // 

  while (1) {

    //
    // main loop 
    //

    if (CUR_MODE == DKTRONICS_M) {      

      SP0256_OFF; 
      EPSON_DK_ON; 

      configure_speak_buffer_timer; 
      start_timer; 

      dk_speech_busy;      
      z80_run; 

      // DK'Tronics Emulation
 
      TRANSMIT_OFF;
      READY_ON; 
      
      while (1) {

	dk_speech_idle_loadme;

	loop_until_bit_is_set(IOREQ_PIN, IOREQ_WRITE_DK); 
	dk_speech_busy; 
	stop_timer;

	_delay_us(3); // don't change... it works

	DATA_FROM_CPC(databus); 	  

	if (databus & 0b10000000 ) {

	  loop_until_bit_is_clear(IOREQ_PIN, IOREQ_WRITE_DK); 

	  if (databus == 0xF0) { 
	    // do nothing for next byte! just for databus LED display 
	    
	    loop_until_bit_is_set(IOREQ_PIN, IOREQ_WRITE_DK); 
	    _delay_us(3); // don't change... it works	    
	    DATA_FROM_CPC(databus); 	  
	    loop_until_bit_is_clear(IOREQ_PIN, IOREQ_WRITE_DK); 

	  } else {

	    z80_halt; 	  
	    process_control(databus); 
	    z80_run; 
	    
	    if (CUR_MODE != LAST_MODE) { 
	      
	      if (CUR_MODE == START_OVER_SAME_MODE)
		CUR_MODE = LAST_MODE; 
	      else
		LAST_MODE = CUR_MODE; 
	      
	      break; 

	    } 
	  }

	} else {

	  _delay_us(15);
	  start_timer; 

	  buffer[length++] = databus;
	  loop_until_bit_is_clear(IOREQ_PIN, IOREQ_WRITE_DK); 

	  if (length == SPEECH_BUFFER_FLUSH_AT)  {
	    speak_buffer(); 
	    if ( STOP_NOW ) {
	      blink_leds(); 
	      STOP_NOW = 0; 
	      tts_stop(); 
	      proceed(); 
	    }
	  }
	}
      }

    } else if (CUR_MODE == SSA1_M) {      

      //
      // SSA1 
      //

      SP0256_OFF; 
      EPSON_SSA1_ON; 

      configure_speak_buffer_timer; 
      start_timer; 

      speech_busy;      
      z80_run; 

      // SSA1 Emulation
 
      TRANSMIT_OFF;
      READY_ON; 
      
      while (1) {

	if (emulated_ssa1_buffer_size == 0) {
	  speech_idle_loadme;
	} else {
	  speech_speaking_loadme;
	}

	loop_until_bit_is_set(IOREQ_PIN, IOREQ_WRITE); 
	speech_busy; 
	stop_timer;

	_delay_us(3); // don't change... it works

	DATA_FROM_CPC(databus); 	  

	if (databus & 0b10000000 ) {

	  loop_until_bit_is_clear(IOREQ_PIN, IOREQ_WRITE); 

	  if (databus == 0xF0) { 
	    // do nothing for next byte! just for databus LED display 
	    
	    loop_until_bit_is_set(IOREQ_PIN, IOREQ_WRITE_DK); 
	    _delay_us(3); // don't change... it works	    
	    DATA_FROM_CPC(databus); 	  
	    loop_until_bit_is_clear(IOREQ_PIN, IOREQ_WRITE_DK); 

	  } else {
	    
	    z80_halt; 	  
	    process_control(databus); 
	    z80_run; 
	    
	    if (CUR_MODE != LAST_MODE) {
	      
	      if (CUR_MODE == START_OVER_SAME_MODE)
		CUR_MODE = LAST_MODE; 
	      else
		LAST_MODE = CUR_MODE; 
	      
	      break; 

	    }
	  }

	} else {

	  _delay_us(15);
	  start_timer; 
	  
	  buffer[length++] = databus;
	  emulated_ssa1_buffer_size = 1; 

	  loop_until_bit_is_clear(IOREQ_PIN, IOREQ_WRITE); 

	  if (length == SPEECH_BUFFER_FLUSH_AT)  {
	    speak_buffer(); 
	    if ( STOP_NOW ) {
	      blink_leds(); 
	      STOP_NOW = 0; 
	      tts_stop(); 
	      proceed(); 
	    }
	  }
	}
      }

    }

#ifndef LS195 

    else if (CUR_MODE == SSA1_SP0_M || CUR_MODE == DKTRONICS_SP0_M) {      

      //
      // SSA1 SP0 
      //

      stop_timer;       

      if (CUR_MODE == SSA1_SP0_M ) {
        SP0256_SSA1_ON; 
      } else { 
        SP0256_DK_ON; 
      }

      z80_run; 
      
      while (1) {

	TRANSMIT_OFF;
	READY_ON;

	loop_until_bit_is_set(IOREQ_PIN, IOREQ_WRITE); 

	// pin = FROM_CPC_OUTPUT; 		
	DATA_FROM_CPC(databus); 

	loop_until_bit_is_clear(IOREQ_PIN, IOREQ_WRITE); 

	TRANSMIT_ON;
	READY_OFF;

	if (databus & 0b10000000 ) {

	  if (databus == 0xF0) { 
	    // do nothing for next byte! just for databus LED display 
	    
	    loop_until_bit_is_set(IOREQ_PIN, IOREQ_WRITE_DK); 
	    _delay_us(3); // don't change... it works	    
	    DATA_FROM_CPC(databus); 	  
	    loop_until_bit_is_clear(IOREQ_PIN, IOREQ_WRITE_DK); 

	  } else {

	    SP0256_OFF; 
	    z80_halt; 	  
	    LAMBDA_EPSON_ON; 
	    process_control(databus); 
	    z80_run; 
	    
	    if (CUR_MODE != LAST_MODE) {
	      
	      if (CUR_MODE == START_OVER_SAME_MODE)
		CUR_MODE = LAST_MODE; 
	      else
		LAST_MODE = CUR_MODE; 
	      
	      break; 
	      
	    } else {

	      if (CUR_MODE == SSA1_SP0_M ) {
		SP0256_SSA1_ON; 
	      } else { 
		SP0256_DK_ON; 
	      }
	      
	    }
	  }

	} else {

	  SEND_TO_SP02; 

	}
      }

    }

#endif 

    else {	 

      //
      // LambdaSpeak native mode - dectalk or epson parser
      // 

      SP0256_OFF; 
      if (CUR_MODE == LAMBDA_EPSON_M ) {
        LAMBDA_EPSON_ON; 
      } else { 
        LAMBDA_DECTALK_ON; 
      }

      stop_timer; 

      uint8_t ctrl = 0; // \xAB, \ = 1, x = 2, A = 3, B = 4 
      uint8_t nibble1 = 0; 
      uint8_t nibble2 = 0; 
      uint8_t log_in = 0; 

      while (1) {

	TRANSMIT_OFF;
	READY_ON;

	speech_native_ready; 
	z80_run; 	
	
	loop_until_bit_is_set(IOREQ_PIN, IOREQ_WRITE); 

	DATA_FROM_CPC(databus); 

	loop_until_bit_is_clear(IOREQ_PIN, IOREQ_WRITE); 

	// note: the ZX Spectrum doesn't like the Z80 wait here...
#ifndef SPECCY	
	z80_halt;
#endif
	
	speech_native_busy;  // to 0... 

	TRANSMIT_ON;
	READY_OFF;

	if (databus & 0b10000000 ) {
	  
	  if (databus == 0xF0) { 
	    // do nothing for next byte! just for databus LED display 
	    
	    loop_until_bit_is_set(IOREQ_PIN, IOREQ_WRITE_DK); 
	    _delay_us(3); // don't change... it works	    
	    DATA_FROM_CPC(databus); 	  
	    loop_until_bit_is_clear(IOREQ_PIN, IOREQ_WRITE_DK); 

	  } else {

	    process_control(databus); 

	    if (!BLOCKING)
	      z80_run; 

	    if (CUR_MODE != LAST_MODE) {

	      if (CUR_MODE == START_OVER_SAME_MODE)
		CUR_MODE = LAST_MODE; 
	      else
		LAST_MODE = CUR_MODE; 
	      
	      break; 
	    }
	    
	  }
	} else {
	  
	  log_in = 0; 
	    
	  if ( databus == '\\' && ctrl == 0 ) {
	    ctrl = 1; 
	  } else if ( ctrl == 1 ) { 
	    if ( databus == 'x' ) {
	      ctrl = 2; 
	    } else {
	      // didn't get \x escape, so log in \ and current: 
	      buffer[length++] = '\\'; 
	      
	      log_in = 1; 
	      ctrl = 0; 
	    }
	  } else if ( ctrl == 2 ) { 
	    if ( databus >= '0' && databus <= '9' ) {
	      nibble1 = databus - '0'; 
	      ctrl = 3; 
	    } else if ( databus >= 'A' && databus <= 'F' ) {
	      nibble1 = databus - 'A'; 
	      ctrl = 3; 
	    } else {
	      // failure to parse \xHEX HEX, ignore! 
	      ctrl = 0; 
	    }
	  } else if ( ctrl == 3 ) {
	    if  ( databus >= '0' && databus <= '9' ) {
	      nibble2 = databus - '0'; 
	      databus = 16*nibble1 + nibble2; 
	      ctrl = 0; 
	      log_in = 1; 
	    } else if ( databus >= 'A' && databus <= 'F' ) {
	      nibble2 = databus - 'A'; 
	      databus = 16*nibble1 + nibble2; 
	      ctrl = 0; 
	      log_in = 1; 
	    } else { 
	      ctrl = 0;  
	    }
	  } else {
	    // normal character
	    ctrl = 0; 
	    log_in = 1; 	    
	  }
	  
	  if (log_in) {

	    buffer[length++] = databus;

	    if (length >= SPEECH_BUFFER_FLUSH_AT)  {
	    
	      if (!BLOCKING)
		z80_run; 

	      speak_buffer(); 

	      if ( STOP_NOW ) {
		blink_leds(); 	      
		STOP_NOW = 0; 
		tts_stop();
		proceed();  
	      }

	    } else if ( databus == 13) {

	      if (!BLOCKING)
		z80_run; 
	    
	      speak_buffer(); 	  

	      if ( STOP_NOW ) {
		blink_leds(); 	      
		STOP_NOW = 0; 
		tts_stop(); 
		proceed(); 
	      }
	    }
	  }
	}
      }
    }

    //
    // main loop  
    // 

  }
 
  return 0;  
   
}

 

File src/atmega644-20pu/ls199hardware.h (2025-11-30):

//
// PINS 
// ================================  

//
// TTS Epson IC Part
// 

#define CS   PB3
#define MOSI PB5
#define MISO PB6
#define SCK  PB7

#define TTS_INPUT  PINB
#define TTS_OUTPUT PORTB
#define TTS_DDR    DDRB

#define S1V30120_RDY    PB0
#define S1V30120_RST    PB2
#define S1V30120_CS     PB3

// All OUTPUT, TTS ClickBoard control, except SCK, 
// and RDY = PB0 and _Z80_READY = PB1 INPUT!  -> 0 = INPUT, 1 = OUTPUT

#define CONFIGURE_TTS_INOUT DDRB  = 0b11111100 

//
// Z80 
// 

#define _Z80_READY PB1 
#define z80_run  DDRB = 0b11111100 
#define z80_halt DDRB = 0b11111110, clearBit(PORTB, _Z80_READY) 

//
// CPC Databus IO 
// 

#define FROM_CPC_OUTPUT PIND 
#define TO_CPC_INPUT    PORTA 
// #define CPC_READ_DELAY  FAST_CPC_GETTERS ? _delay_us(50) :  _delay_ms(50) 

// all output 
#define CONFIGURE_TO_CPC_INPUT     DDRA  = 0b11111111 

// all input, no pullups 
#define CONFIGURE_FROM_CPC_OUTPUT  DDRD  = 0b00000000; PORTD  = 0b00000000 

//
// Master DATABUS MACRO 
// 

static volatile uint8_t synchro = 0; 

#define DATA_TO_CPC(arg)    TO_CPC_INPUT = arg 
#define DATA_FROM_CPC(arg)  arg = FROM_CPC_OUTPUT 

//
// Virtual SSA1 PINs - MUST BE ON TO_CPC_INPUT !
// 

#define _LRQ PA6 
#define SBY  PA7  

#define NATIVE_SBY  PA5

//
// DKtronics Signals 
// 

#define dk_speech_idle_loadme        TO_CPC_INPUT = 0 
#define dk_speech_busy               setBit(TO_CPC_INPUT, SBY)

//
// SSA1 Signals 
// 


#define speech_idle_loadme      clearBit(TO_CPC_INPUT, _LRQ),   setBit(TO_CPC_INPUT, SBY)  
#define speech_busy               setBit(TO_CPC_INPUT, _LRQ), clearBit(TO_CPC_INPUT, SBY)  
#define speech_speaking_loadme  clearBit(TO_CPC_INPUT, _LRQ), clearBit(TO_CPC_INPUT, SBY)  


//#define speech_idle_loadme       synchro = 0; setBit(synchro, SBY);  DATA_TO_CPC(synchro) 
//#define speech_busy              synchro = 0; setBit(synchro, _LRQ); DATA_TO_CPC(synchro) 
//#define speech_speaking_loadme   synchro = 0; DATA_TO_CPC(synchro) 

//
// Native Signals - Can be used to determine if LambdaSpeak is still speaking, from CPC side 
// Only makes sense in non-blocking mode of course 
// In blocking mode, the CPC ist halted by pulling Z80 Wait to ground!
// 

#define speech_native_ready      synchro = 0; setBit(synchro, NATIVE_SBY); DATA_TO_CPC(synchro) 
#define speech_native_busy       synchro = 0; DATA_TO_CPC(synchro) 

//
// CPC Data WRite - From Address Decoder! Trigger 
// 

#define IOREQ_PIN      PINC

#define IOREQ_WRITE    PC7 
#define IOREQ_WRITE_DK PC7

//
// Soft Reset Button and LEDs 
// 

// PC6 = D22 
#define SOFT_RESET_INT PCINT22 
#define SOFT_RESET_INT_VEC PCINT2_vect
#define SOFT_RESET_PIN PINC
#define SOFT_RESET_PIN_NUMBER PC6

// pullup for reset!
#define CONFIGURE_RESET PORTC |= 0b01000000 

//
//
// 

#define LED_PORT_READY    PORTC
#define LED_PORT_TRANSMIT PORTC
#define READY_LED    PC0
#define TRANSMIT_LED PC1

// PC2 = Amdrum, PC1 = LED, PC0 = LED, 1 = OUTPUT, PC5 = SP0256, PC4 = SP0256_SSA1_MODE, PC3 = SP0256_DK_MODE 
// only PC6 and PC7 ARE INPUTS (RESET FROM BUTTON AND WRITE REQ FROM CPLD) 

#define CONFIGURE_LEDS DDRC = 0b00111111 
#define CONFIGURE_SP0  DDRC = 0b00111111 

//
// PCM AUDIO 
//

#define PCM_PIN PB4 
#define CONFIGURE_PCM DDRB |= ( 1 << PB4); // = OC0B = PB4 = AMDRUM AUDIO OUTPUT

//
//
//

#define AMDRUM_PORT    PORTC 
#define AMDRUM_ENABLED PC2 

//
// SP0256 IN/OUT
//

#define SP0256_ENABLE_PORT  PORTC 
// hardware enable for SP0256 
#define SP0256_ENABLED      PC5 
// to CPLD: 

// to CPLD: 
#define SSA1_MODE    PC4
// to CPLD: 
#define DK_MODE      PC3 

//#define SP0256_SSA1_MODE    PC4
// to CPLD: 
//#define SP0256_DK_MODE      PC3 

#define SP0256_DATA_PORT    PORTA 

//
//
//

#define DATA_TO_SP0(arg)      SP0256_DATA_PORT = arg 
#define STATUS_FROM_SP0(arg)  arg = SP0256_INPUT_PIN 

// ================================
// END PINS 
// 

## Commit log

2018-04-20 Initial commit. Still some content missing.
    [lambdaspeak195-B.Cu.gbl, lambdaspeak195-B.Mask.gbs, lambdaspeak195-B.SilkS.gbo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]
2018-04-26 README.md update - TFM's driver software
2018-04-26 Screenshot LamdbdaSpeak Driver TFM
2018-06-27 Firmware LS199 + LS21 update - SPO256-AL2 initalization glitch bugfix. Bugfix flush delay getter method. Bump version to 6. Newest version of TFM's driver added.
2018-07-24 Firmware bugfix - DKtronics mode didn't work in LS195 and LS20 firmware. Wrong input pin...
2019-02-18 Adding fuse bits settings for flashing JED with standard MiniPro Programmer.
2025-07-10 Microprofessor backplane adapter Gerbers.
2026-09-11 Fix spelling in the documentation
    LambdaSpaak, LamdaSpeak -> LambdaSpeak maximimum -> maximum
    DKtronic -> DK'tronics misscalculation -> miscalculation
    Stero -> Stereo osscillator -> oscillator
    Wiliams -> Williams paramerts -> parameters
    Hompage -> Homepage reprogramm -> reprogram
    asychronous -> asynchronous toggeling -> toggling
    currrent -> current switche on -> switched on
    emulatation -> emulation plattform -> platform
    epansion -> expansion driver softwares -> driver software
    exentsion -> extension immediatl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
2026-09-20 Latest News: the 1985 Vector Head speaks, on LambdaSpeak
    The head digitized by hand off a P.M. Computerheft article in 1985 has been
    rewritten in Z80, animated, and given a voice through the SP0256-AL2 - with
    the letter-to-sound rules taken from the 1985 SSA-1 driver, so it runs on
    LambdaSpeak in SSA-1 mode. Both demo videos linked.
    Claude-Session: https://claude.ai/code/session_01NYwNLJv4mWCnQH4g3MmoLD
2026-09-21 Vector Head: the disc images, and how to run them
    head.dsk and head.hfe under cpc/vectorhead/, announced in the news entry,
    with a short note on running it - in particular RUN"VH and not RUN"HEAD,
    since VH.BAS is what loads the letter-to-sound engine and without it there
    is no prompt. The assembler source stays private for now.
    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

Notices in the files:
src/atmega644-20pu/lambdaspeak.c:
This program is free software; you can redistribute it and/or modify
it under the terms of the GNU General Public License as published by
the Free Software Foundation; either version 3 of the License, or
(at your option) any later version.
